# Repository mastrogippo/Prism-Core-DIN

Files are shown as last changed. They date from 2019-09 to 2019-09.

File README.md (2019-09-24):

## Prism Core boards and accessories

[Writeup and pics here](https://www.mastrogippo.it/2019/09/prism-core-boards/)

cover_pcb: Cover board layout

hv_in3: Base high voltage board for Prism Core

lato1: Left board with relay and HV detection for Prism Core

latoLV: Low voltage side board for Prism Core

top: Tob board with SKW92 module for Prism Core

top_hk2: Top board with HiLink module and RTC for Prism Core

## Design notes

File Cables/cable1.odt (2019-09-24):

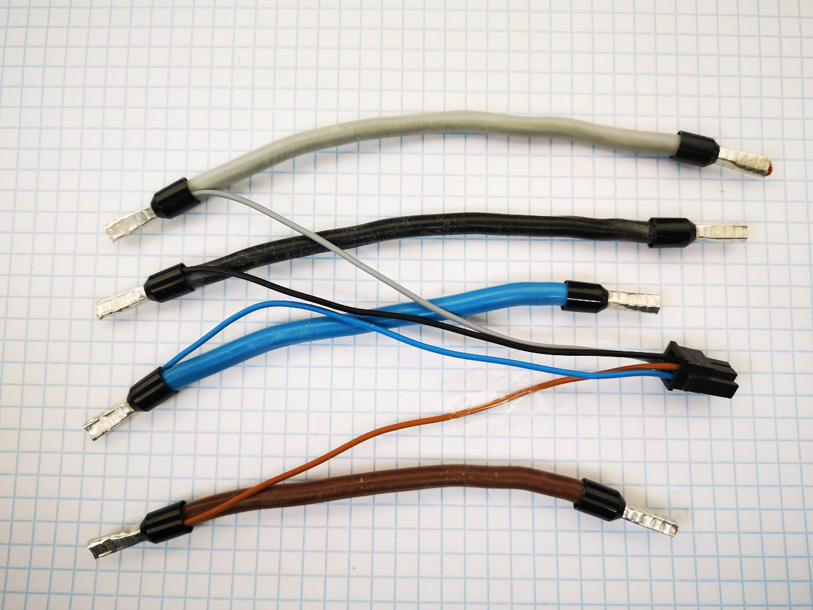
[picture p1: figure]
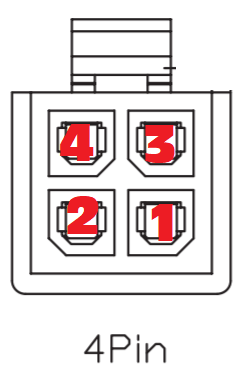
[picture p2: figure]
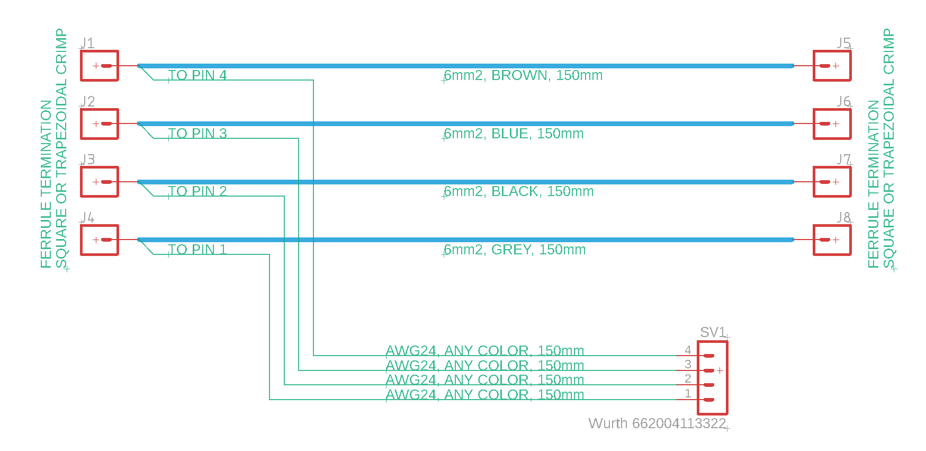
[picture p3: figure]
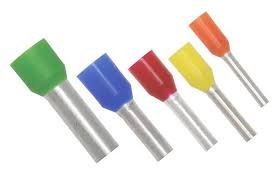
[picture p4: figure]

Connector: Wurth Electronics 662004113322
PINOUT SHOWN FROM BACK OF CONNECTOR

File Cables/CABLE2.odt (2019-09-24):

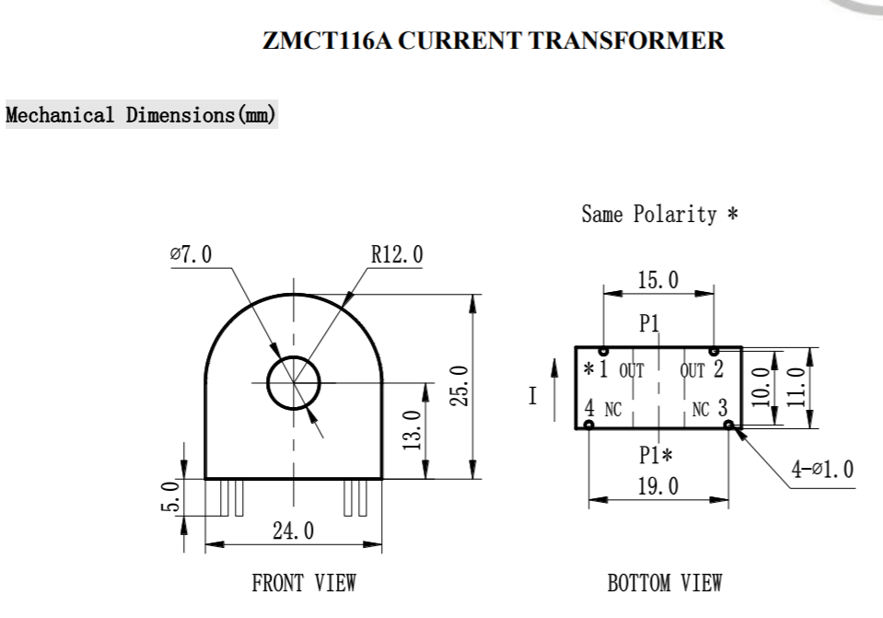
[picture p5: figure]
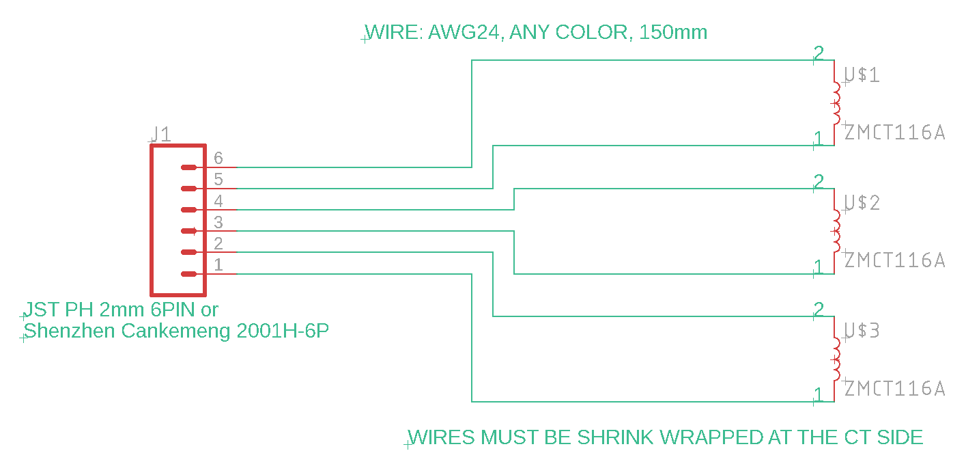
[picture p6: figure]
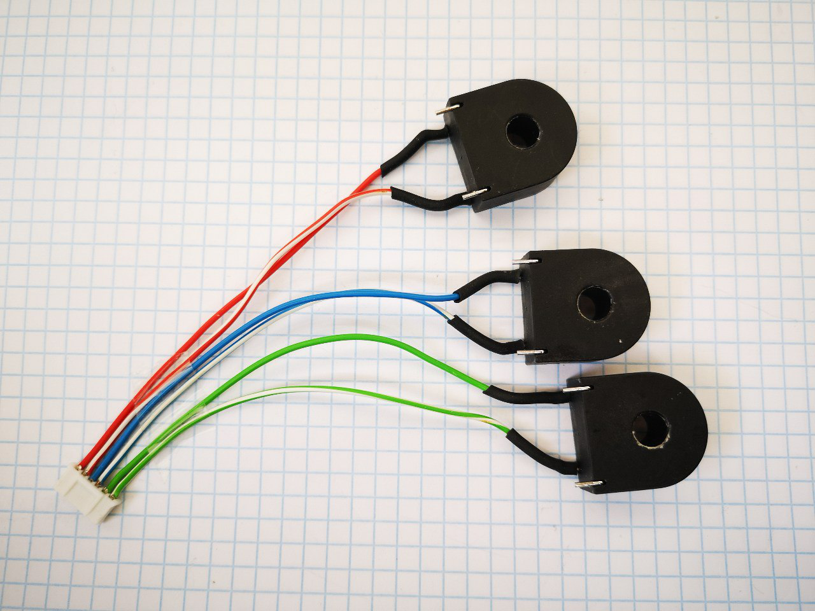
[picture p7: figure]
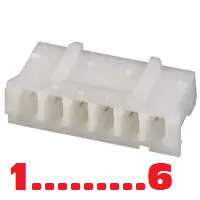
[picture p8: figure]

CONNECTOR:

SC 2001H-6P

https://lcsc.com/product-detail/_Shenzhen-Cankemeng-2001H-6P_C132488.html

(https://www.digikey.it/products/en?mpart=PHR-6&v=455)

JST PHR-6

https://www.digikey.it/products/en?mpart=PHR-6&v=455

WIRES MUST BE SHRINK WRAPPED AT THE CT SIDE (SEE PICTURE)

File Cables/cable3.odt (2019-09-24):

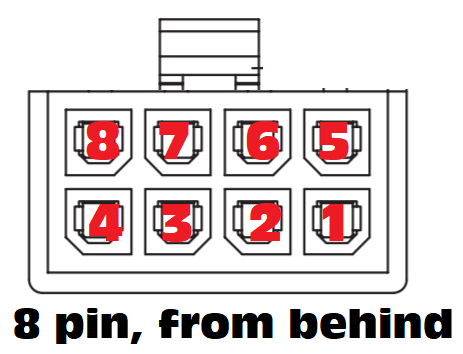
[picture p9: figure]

CONNECTOR: WURTH 662 008 113 322

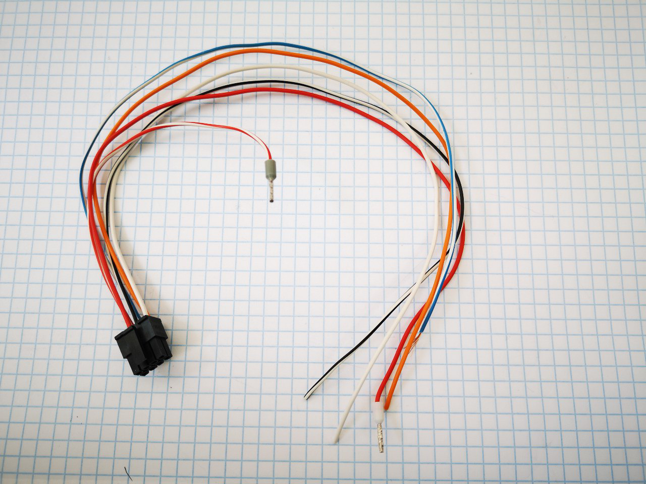
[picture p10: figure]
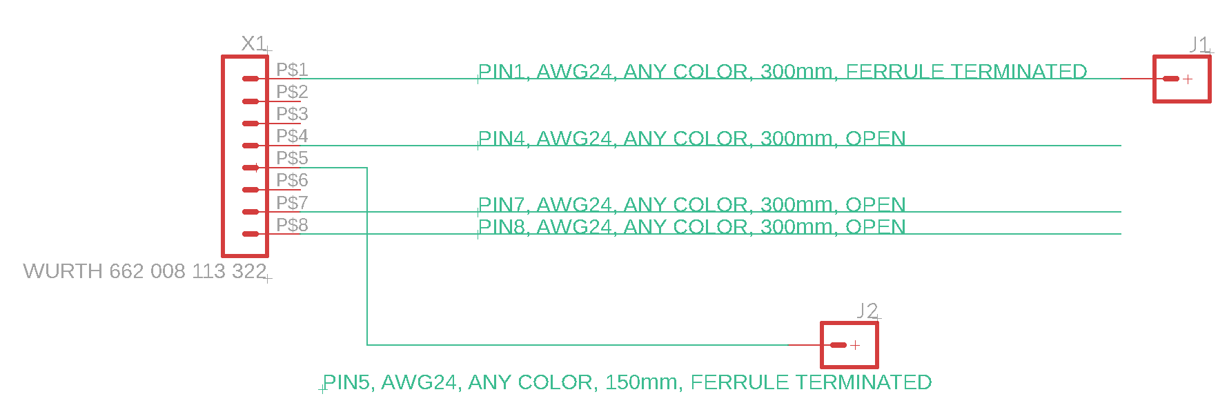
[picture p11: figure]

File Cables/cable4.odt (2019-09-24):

WARNING! PINS ARE INVERTED FROM ONE CONNECTOR 1 TO CONNECTOR 2 (1-4, 2-3, 3-2, 4-1, NOTE INVERTED CONNECTOR IN PICTURE)

https://lcsc.com/product-detail/_Shenzhen-Cankemeng-2001H-4P_C126370.html

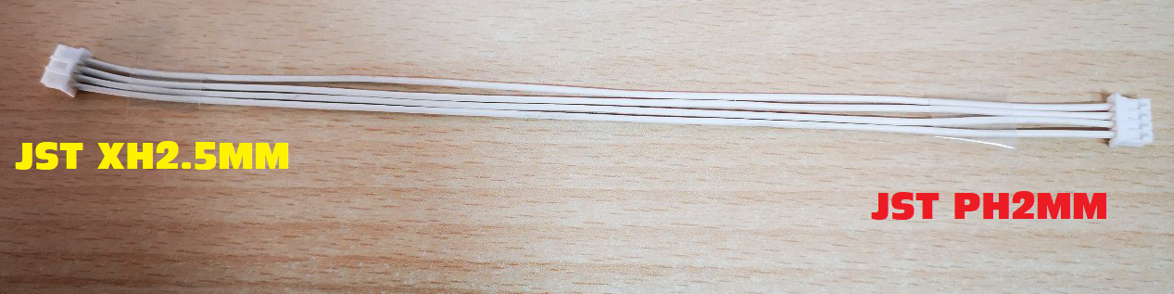
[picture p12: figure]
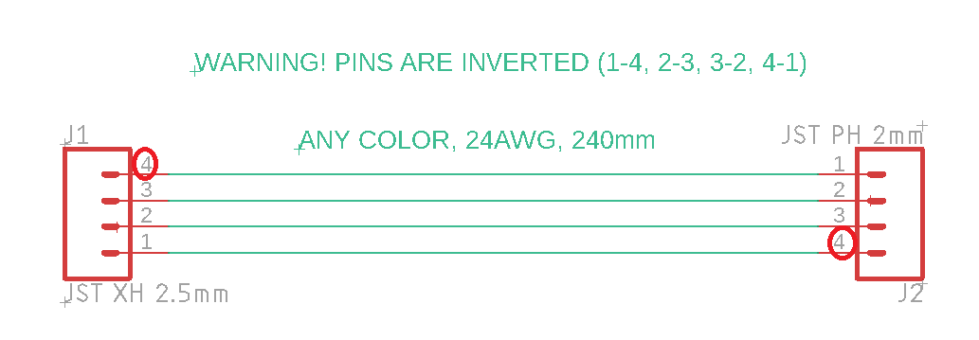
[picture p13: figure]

https://lcsc.com/product-detail/_JST-Sales-America_XHP-4_JST-Sales-America-XHP-4_C144403.html

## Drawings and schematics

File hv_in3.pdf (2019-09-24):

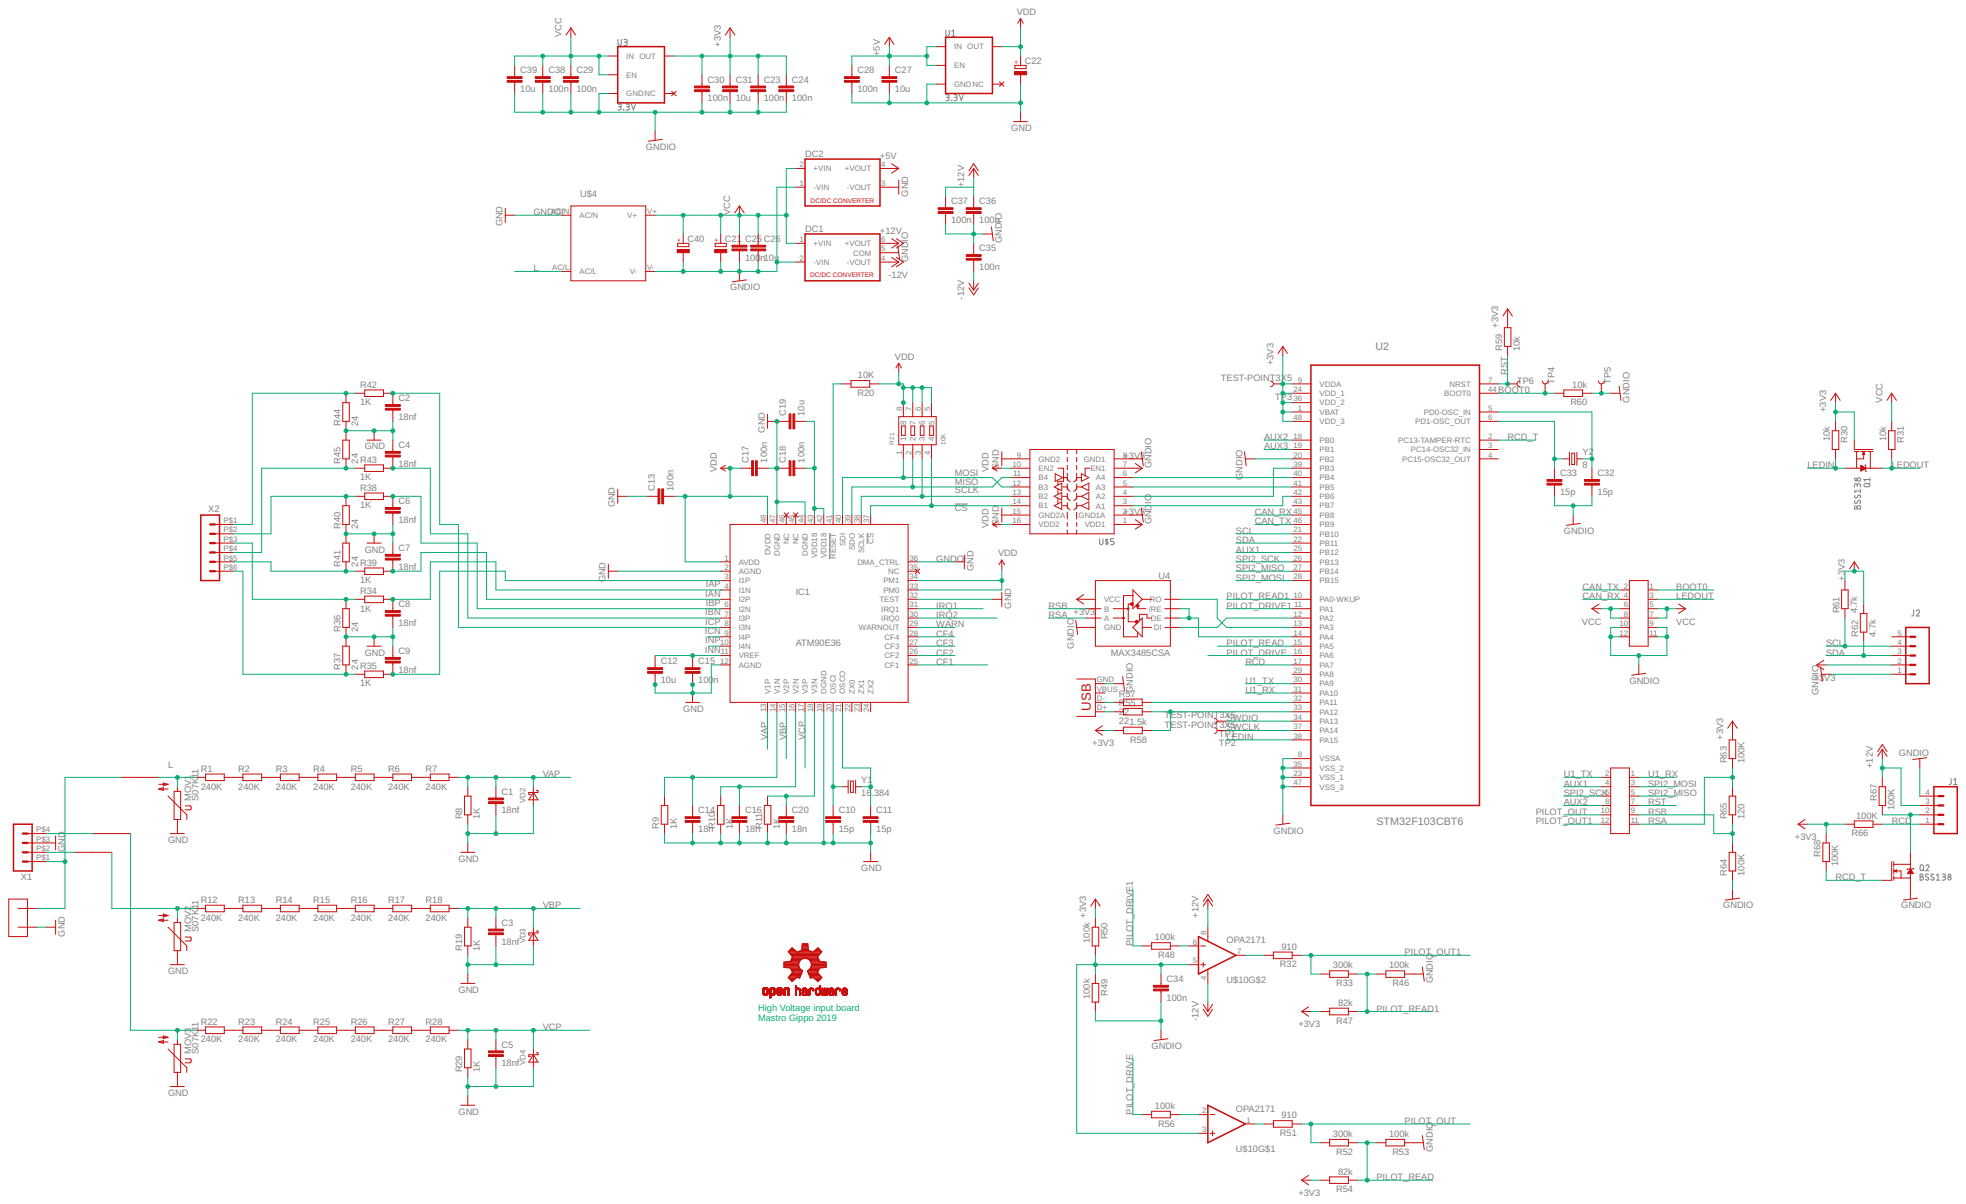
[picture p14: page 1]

+ High Voltage input board Mastro Gippo 2019

SCLK CSMOSI MISO | 7 GND1A 5 A4

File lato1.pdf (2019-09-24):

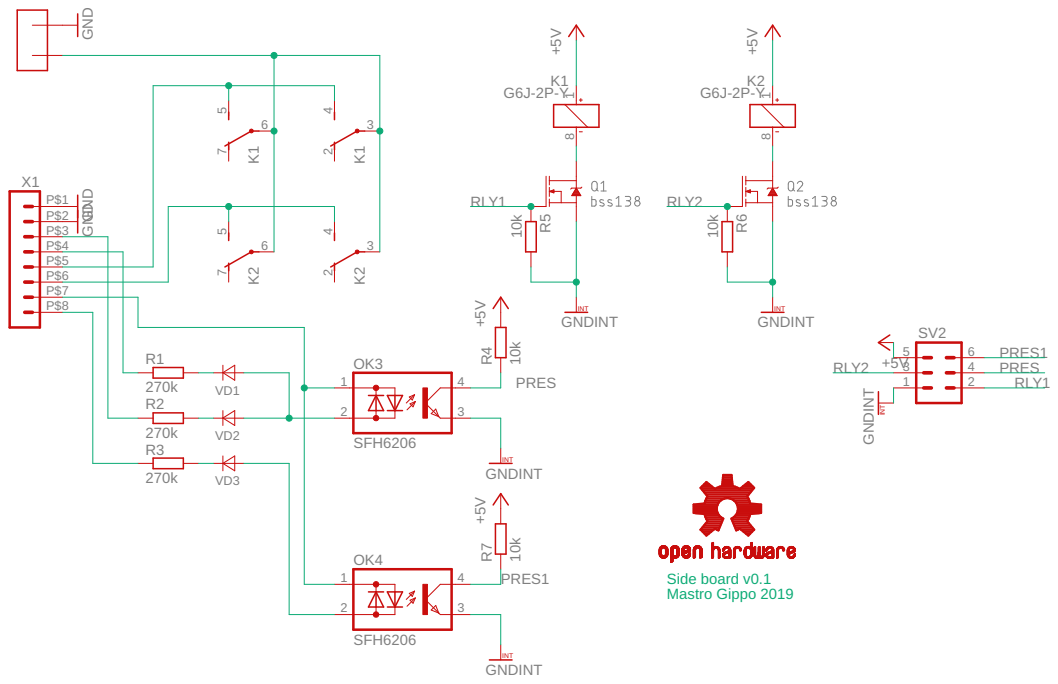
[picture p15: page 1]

GND G6J-2P-Y G6J-2P-Y GND 270k 270k 270k GND +5V +5V 10k 10k 10k +5V GNDINT GNDINT GNDINT GNDINT +5V +5V 10k GNDINT SFH6206 SFH6206 P$1 P$2 P$3 P$4 P$5 P$6 P$7 P$8 X1 8 1 K1 2 4 3K71 5 6K1 8 1 K2 2 4 3K72 5 6K2 R1 R2 R3 135 246 SV2 VD2 VD1 VD3 R4 R5 R6 R7 12 34 OK3 12 34 OK4 PRES PRES RLY1 RLY1 RLY2 RLY2 PRES1 PRES1 INT INT INT INT INT Side board v0.1 Mastro Gippo 2019

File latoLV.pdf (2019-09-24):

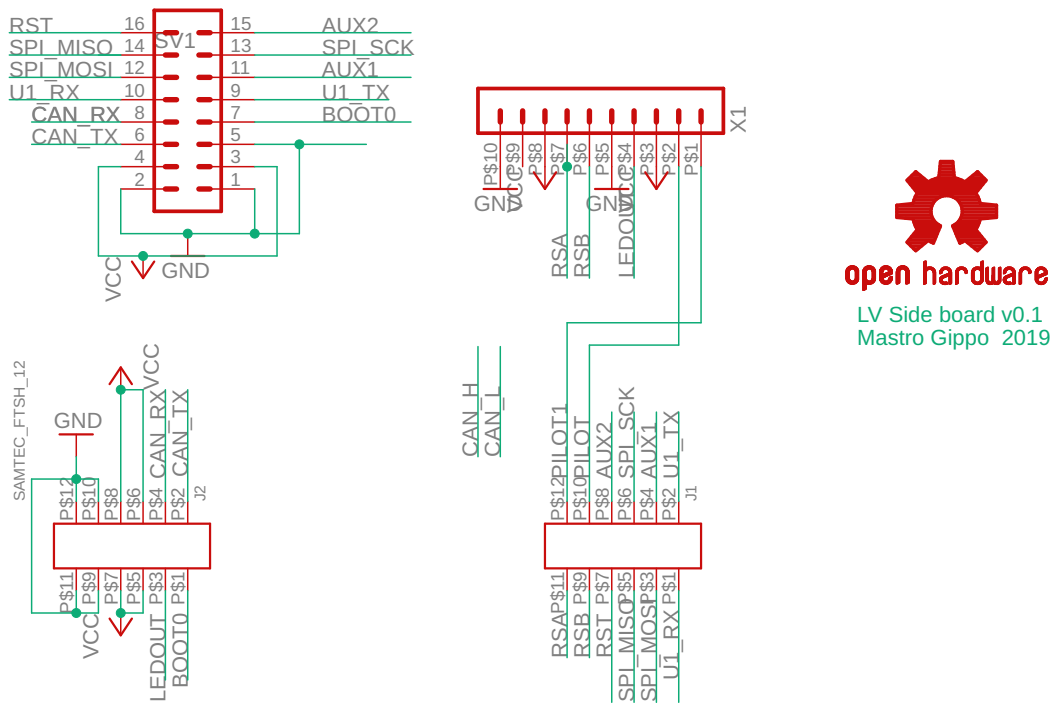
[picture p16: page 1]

SAMTEC_FTSH_12 GNDVCC VCC GND VCC VCC VCC GND GND P$1 P$2 P$3 P$4 P$5 P$6 P$7 P$8 P$9 P$10 P$11 P$12 J1 P$1 P$2 P$3 P$4 P$5 P$6 P$7 P$8 P$9 P$10 P$11 P$12 J2 135 246 79 810 111315 121416 SV1 P$1 P$2 P$3 P$4 P$5 P$6 P$7 P$8 P$9 P$10 X1 CAN_RX CAN_RX CAN_TX CAN_TX LEDOUT LEDOUT BOOT0 BOOT0 RSA RSA RSB RSB RST RST SPI_MISO SPI_MISO SPI_MOSI SPI_MOSI U1_RX U1_RX U1_TX U1_TX AUX1 AUX1 SPI_SCK SPI_SCK AUX2 AUX2 PILOT PILOT1 CAN_H CAN_L LV Side board v0.1 Mastro Gippo 2019

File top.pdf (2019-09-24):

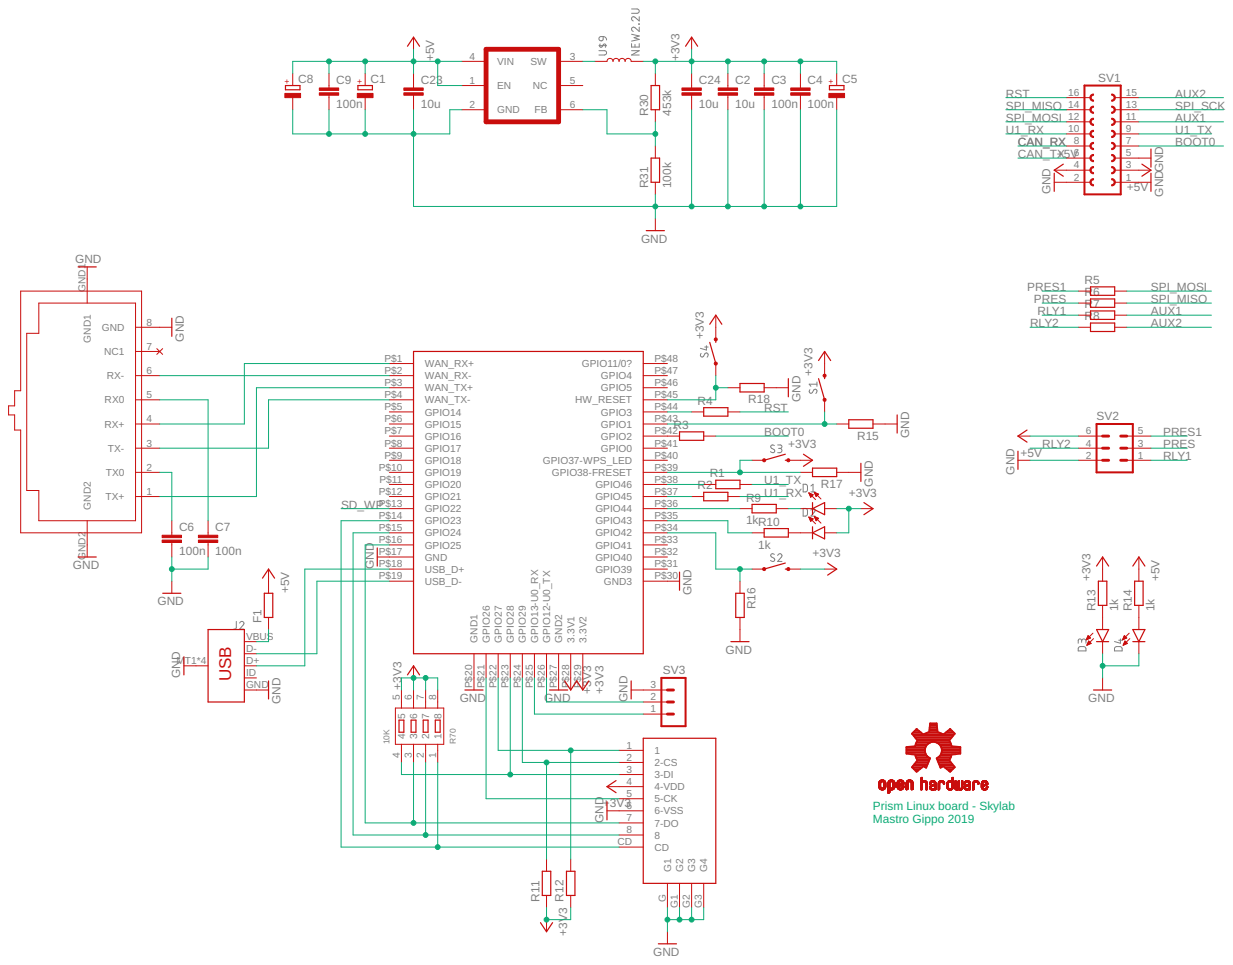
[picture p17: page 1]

3-DI 3

Prism Linux board - Skylab
Mastro Gippo 2019

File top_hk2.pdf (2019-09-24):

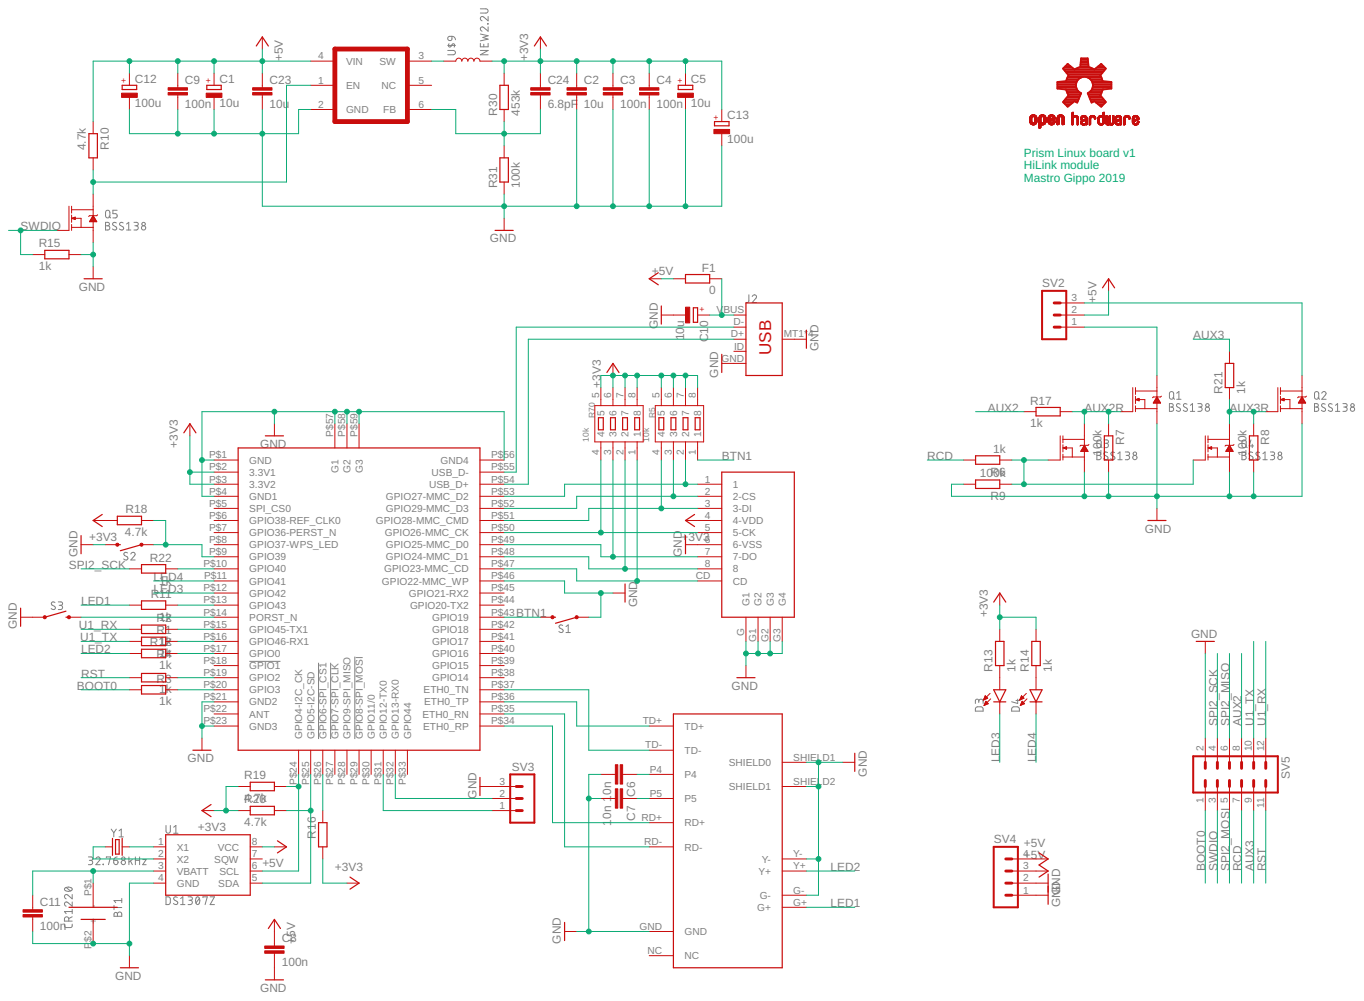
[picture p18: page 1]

Prism Linux board v1
HiLink module Mastro Gippo 2019

P$50 GPIO27-MMC_D2 P$53 GPIO28-MMC_CMD | 3-DI 3

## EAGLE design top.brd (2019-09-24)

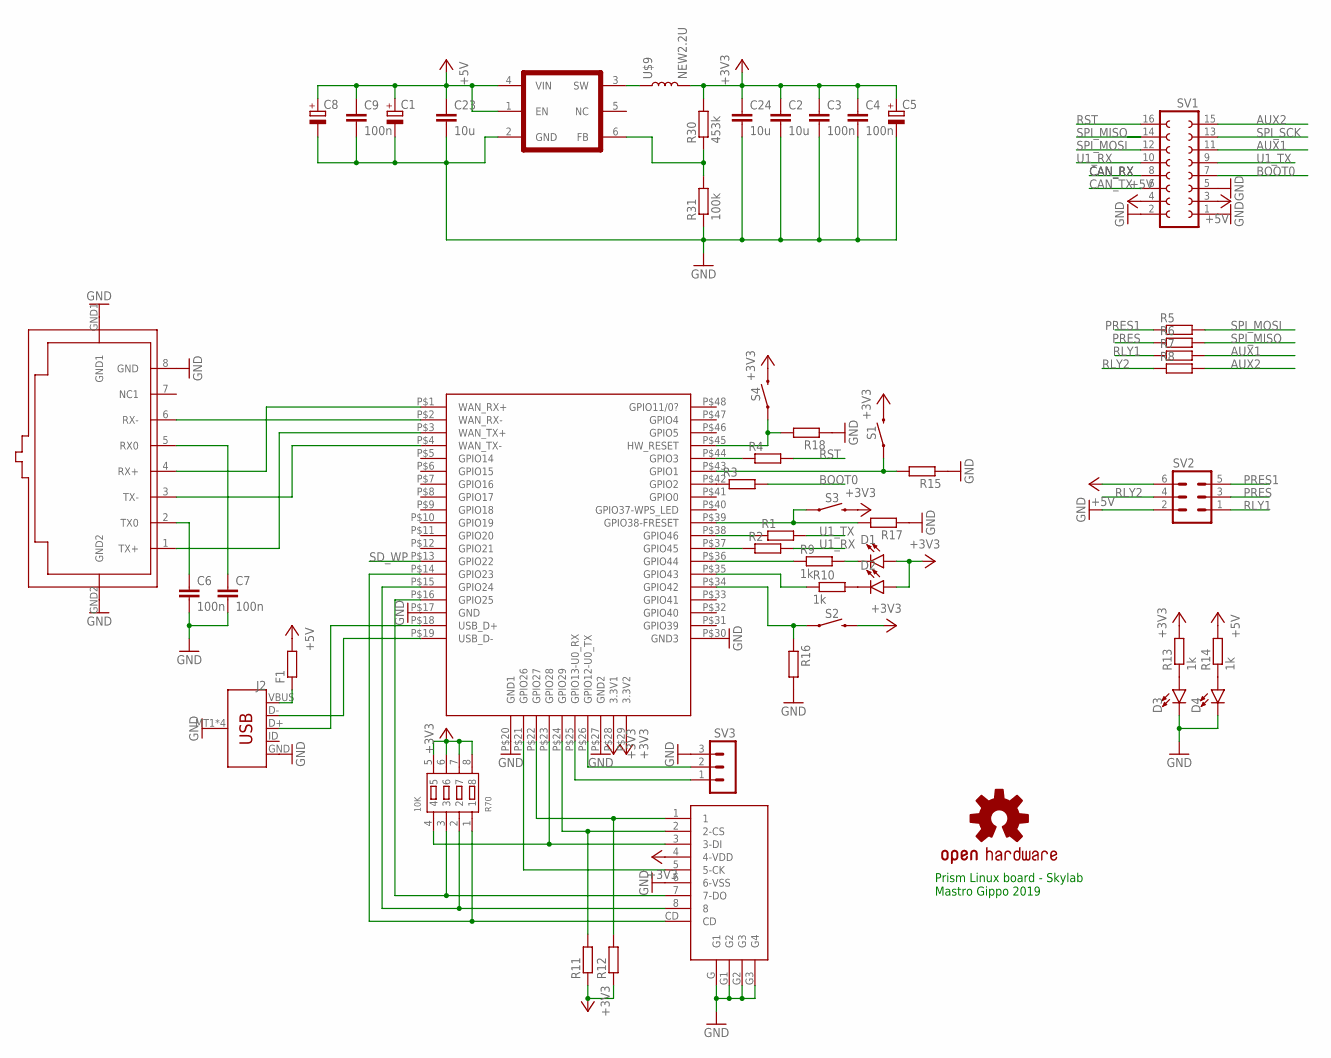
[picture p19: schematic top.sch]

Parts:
C1, C5, C8: CPOL-EUB/3528-21R; B/3528-21R
C2, C23, C24: 10u; C0805K
C3, C4, C6, C7, C9: 100n; C0805K
D1, D2: LED3MM; LED_3MM
D3, D4: LED1206; LED-1206
F1: R-EU_R0603; R0603
J2: USB_MICRO-B_SMT; USB-MICROB
R1, R2, R3, R4, R5, R6, R7, R8, R11, R12, R15, R16, R17, R18: R-EU_R0805; R0805
R9, R10, R13, R14: 1k; R0805
R30: 453k; R0805
R31: 100k; R0805
R70: 10K; RA1206-8
S1, S2, S4: MOMENTARY-SWITCH-SPST-SMD-6.0X3.5MM; TACTILE_SWITCH_SMD_6.0X3.5MM
S3: MOMENTARY-SWITCH-SPST-PTH-RIGHT-ANGLE; TACTILE_SWITCH_PTH_RIGHT_ANGLE
SV1: FE08-2
SV2: MA03-2
SV3: MA03-1
U$1: RJ45-TRAFO
U$2: SKW92B; SKW92
U$3: MICRO_SD; MICRO_SD_C
U$4: OSHW-LOGOS; OSHW-LOGO-S
U$8: TLV62658; SOT23-6
U$9: NEW2.2U; INDUCTOR_4X4MM

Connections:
+3V3: C2.1, C3.1, C4.1, C5.+, C24.1, D1.A, D2.A, R11.1, R12.1, R13.2, R30.2, R70.5, R70.6, R70.7, R70.8, S1.2, S2.2, S3.2, S4.2, U$2.P$28 (3.3V1), U$2.P$29 (3.3V2), U$3.4 (4-VDD), U$9.P$2 (2)
+5V: C1.+, C8.+, C9.1, C23.1, F1.2, R14.2, SV1.3, SV1.4, SV2.6, U$8.1 (EN), U$8.4 (VIN)
AUX1: R7.2, SV1.11
AUX2: R8.2, SV1.15
BOOT0: R3.2, SV1.7
CAN_RX: SV1.8
CAN_TX: SV1.6
GND: C1.-, C2.2, C3.2, C4.2, C5.-, C6.2, C7.2, C8.-, C9.2, C23.2, C24.2, D3.C, D4.C, J2.GND, J2.MT1 (SHIELD), J2.MT2 (SHIELD), J2.P$1 (SHIELD), J2.P$2 (SHIELD), R15.1, R16.2, R17.1, R18.1, R31.1, SV1.1, SV1.2, SV1.5, SV2.2, SV3.3, U$1.8 (GND), U$1.GND1, U$1.GND2, U$2.P$17 (GND), U$2.P$20 (GND1), U$2.P$27 (GND2), U$2.P$30 (GND3), U$3.6 (6-VSS), U$3.G (G1), U$3.G1 (G2), U$3.G2 (G3), U$3.G3 (G4), U$8.2 (GND)
unnamed: U$1.6 (RX-), U$2.P$2 (WAN_RX-)
unnamed: U$1.4 (RX+), U$2.P$1 (WAN_RX+)
unnamed: U$1.1 (TX+), U$2.P$3 (WAN_TX+)
unnamed: U$1.3 (TX-), U$2.P$4 (WAN_TX-)
unnamed: R11.2, U$2.P$24 (GPIO29), U$3.2 (2-CS)
unnamed: R70.4, U$2.P$23 (GPIO28), U$3.3 (3-DI)
unnamed: R12.2, U$2.P$22 (GPIO27), U$3.1
unnamed: U$2.P$21 (GPIO26), U$3.5 (5-CK)
unnamed: R70.3, U$2.P$16 (GPIO25), U$3.7 (7-DO)
unnamed: R70.2, U$2.P$15 (GPIO24), U$3.8
unnamed: R70.1, U$2.P$14 (GPIO23), U$3.CD
unnamed: R1.1, U$2.P$38 (GPIO46)
unnamed: R2.1, U$2.P$37 (GPIO45)
unnamed: R3.1, U$2.P$42 (GPIO2)
unnamed: R4.1, U$2.P$44 (GPIO3)
unnamed: D1.K (C), R9.2
unnamed: SV3.2, U$2.P$26 (GPIO12-U0_TX)
unnamed: SV3.1, U$2.P$25 (GPIO13-U0_RX)
unnamed: D2.K (C), R10.2
unnamed: R9.1, U$2.P$36 (GPIO44)
unnamed: R10.1, U$2.P$35 (GPIO43)
unnamed: D3.A, R13.1
unnamed: D4.A, R14.1
unnamed: R15.2, S1.1, U$2.P$43 (GPIO1)
unnamed: R16.1, S2.1, U$2.P$34 (GPIO42)
unnamed: R17.2, S3.1, U$2.P$39 (GPIO38-FRESET)
unnamed: R18.2, S4.1, U$2.P$45 (HW_RESET)
unnamed: C7.1, U$1.5 (RX0)
unnamed: C6.1, U$1.2 (TX0)
unnamed: J2.D+, U$2.P$18 (USB_D+)
unnamed: J2.D-, U$2.P$19 (USB_D-)
unnamed: F1.1, J2.VBUS
unnamed: U$8.3 (SW), U$9.P$1 (1)
unnamed: R30.1, R31.2, U$8.6 (FB)
PRES: R6.1, SV2.3
PRES1: R5.1, SV2.5
RLY1: R7.1, SV2.1
RLY2: R8.1, SV2.4
RST: R4.2, SV1.16
SD_WP: U$2.P$13 (GPIO22)
SPI_MISO: R6.2, SV1.14
SPI_MOSI: R5.2, SV1.12
SPI_SCK: SV1.13
U1_RX: R2.2, SV1.10
U1_TX: R1.2, SV1.9

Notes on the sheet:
Prism Linux board - Skylab Mastro Gippo 2019

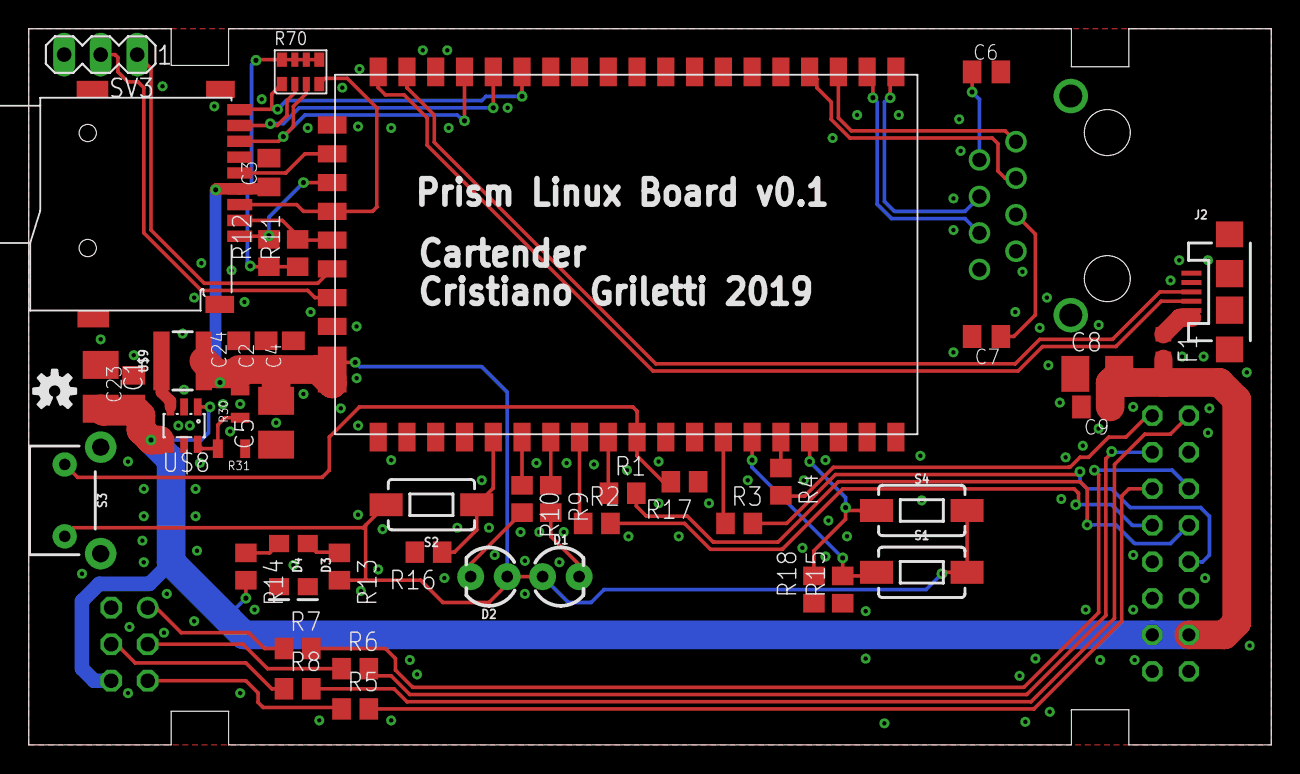
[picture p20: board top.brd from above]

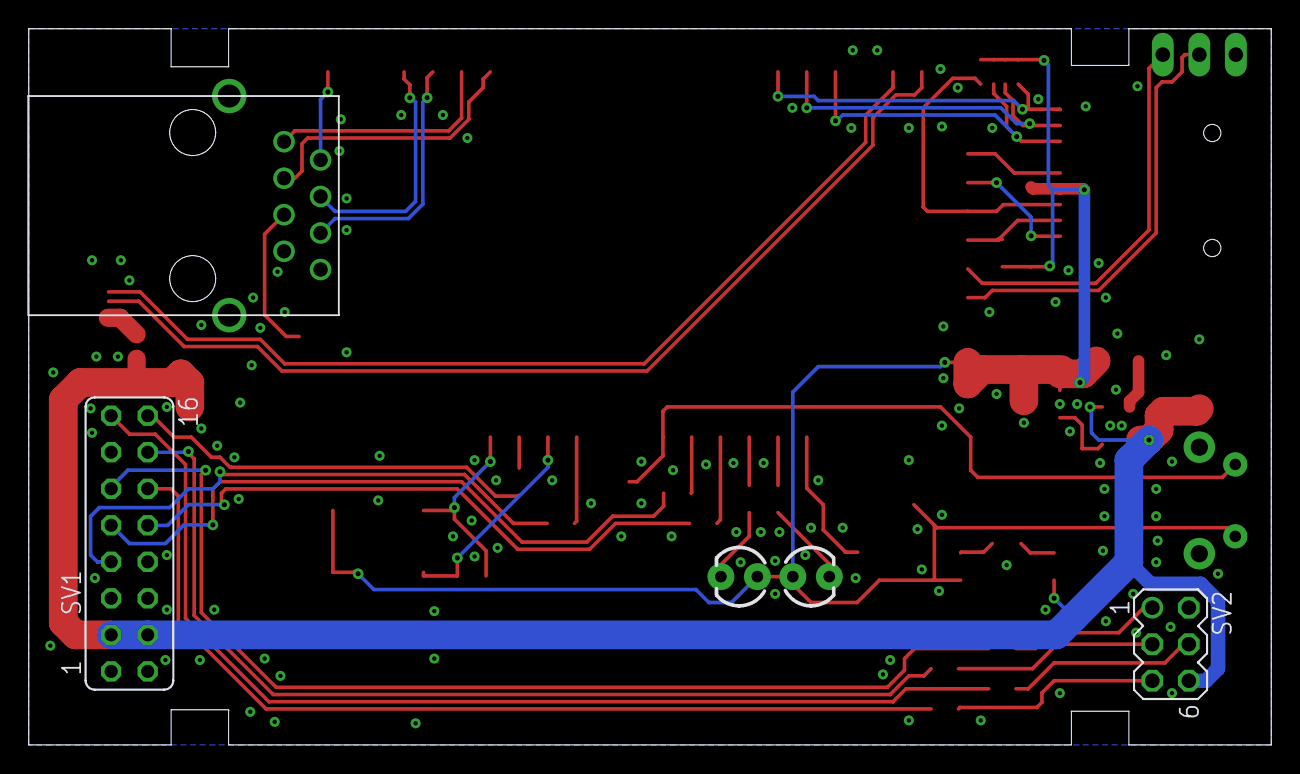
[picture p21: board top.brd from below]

Board: 2 copper layers, 86.4 x 49.8 mm, 51 parts (3 on the bottom side), 49 nets.

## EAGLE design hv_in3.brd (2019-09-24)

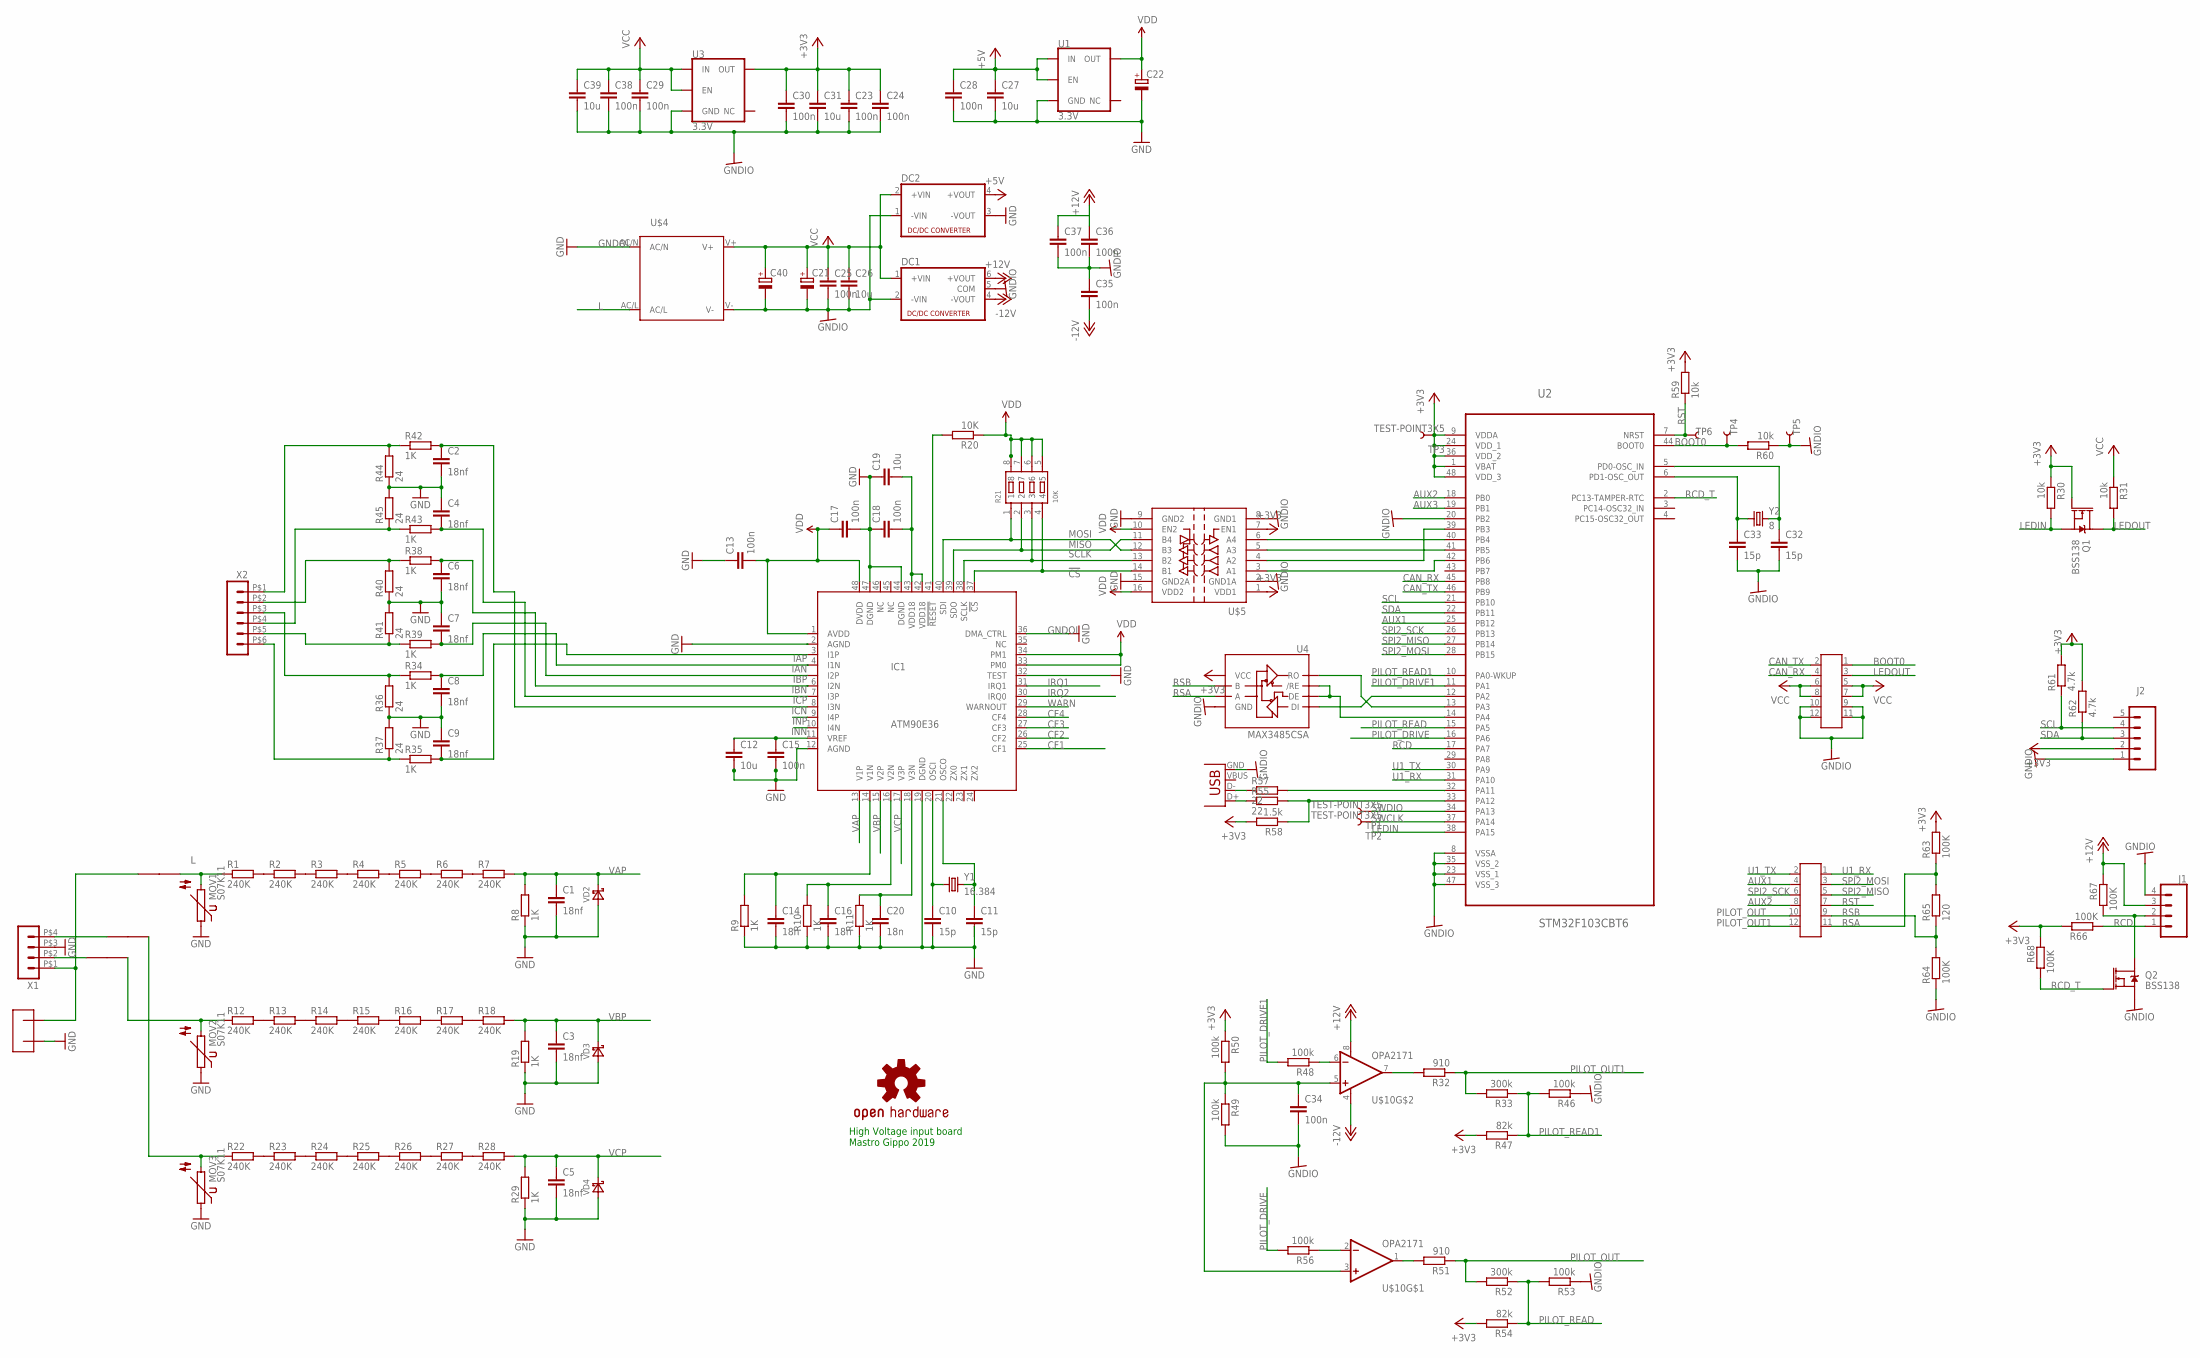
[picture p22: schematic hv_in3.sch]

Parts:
C1, C2, C3, C4, C5, C6, C7, C8, C9: 18nf; C0805K
C10, C11, C32, C33: 15p; C0805K
C12, C19, C26, C27, C31, C39: 10u; C0805K
C13, C15, C17, C18, C23, C24, C25, C28, C29, C30, C34, C35, C36, C37, C38: 100n; C0805K
C14, C16, C20: 18n; C0805K
C21, C22: CPOL-EU153CLV-0505; 153CLV-0505
C40: CPOL-EUB/3528-21R; B/3528-21R
DC1: NMA
DC2: NME
IC1: ATM90E36; TQFP48
J1: CONN_04SMD2; 1X04_1MM_RA
J2: CONN_05SMD2; 1X05_1MM_RA
MOV1, MOV2, MOV3: S07K11
Q1, Q2: BSS138; SOT23-3
R1, R2, R3, R4, R5, R6, R7, R12, R13, R14, R15, R16, R17, R18, R22, R23, R24, R25, R26, R27, R28: 240K; R0805
R8, R9, R10, R11, R19, R29, R34, R35, R38, R39, R42, R43: 1K; R0805
R20: 10K; R0805
R21: 10K; RA1206-8
R30, R31, R59, R60: 10k; R0805
R32, R51: 910; R1206
R33, R52: 300k; R0805
R36, R37, R40, R41, R44, R45: 24; R0805
R46, R48, R49, R50, R53, R56: 100k; R0805
R47, R54: 82k; R0805
R55, R57: 22; R0805
R58: 1.5k; R0805
R61, R62: 4.7k; R0805
R63, R64, R66, R67, R68: 100K; R0805
R65: 120; R0805
TP1, TP2, TP3, TP4, TP5, TP6: TEST-POINT3X5; PAD.03X.05
U1, U3: 3.3V; SOT23-5
U2: STM32F103CBT6; QFP50P900X900X160-48N
U4: MAX3485CSA; SO08
U$1, U$2, U$3: FUSE_2410; 2410_F
U$4: IRM_15/20IRM_15/20; IRM_15/20
U$5: SI8441IS1; SO16
U$6: ISOLATED_2P; STRIP_NOMIDDLE
U$7, U$8: CLP-106-02-F-D-P; CLP-106-02-X-D
U$9: OSHW-LOGOS; OSHW-LOGO-S
U$10: OPA2171; SO08
VD2, VD3, VD4: DIODE-SCHOTTKY-SOD523; SOD523
X1: HEADER_POS4_43045-0401; 43045-0400
X2: HEADER_POS6_43045-0600; 43045-0600
X3: USB-MICROB
Y1: 16.384; CRYSTAL-SMD-3.2X2.5MM
Y2: 8; CRYSTAL-SMD-3.2X2.5MM

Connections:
!CS: IC1.37 (!CS), R21.4, U$5.14 (B1)
+3V3: C23.1, C24.1, C30.1, C31.1, J2.2, Q1.1 (G), R30.1, R47.2, R50.1, R54.2, R58.2, R59.2, R61.2, R62.2, R63.2, R66.2, R68.2, TP3.P$1, U2.1 (VBAT), U2.9 (VDDA), U2.24 (VDD_1), U2.36 (VDD_2), U2.48 (VDD_3), U3.5 (OUT), U4.8 (VCC), U$5.1 (VDD1), U$5.7 (EN1)
+5V: C27.1, C28.1, DC2.4 (+VOUT), U1.1 (IN), U1.3 (EN)
+12V: C36.1, C37.1, DC1.6 (+VOUT), J1.3, R67.2, U$10.8 (V+)
-12V: C35.2, DC1.4 (-VOUT), U$10.4 (V-)
AUX1: U2.25 (PB12), U$7.4
AUX2: U2.18 (PB0), U$7.8
AUX3: U2.19 (PB1)
BOOT0: R60.2, TP4.P$1, U2.44 (BOOT0), U$8.1
CAN_RX: U2.45 (PB8), U$8.4
CAN_TX: U2.46 (PB9), U$8.2
CF1: IC1.25 (CF1)
CF2: IC1.26 (CF2)
CF3: IC1.27 (CF3)
CF4: IC1.28 (CF4)
GNDIO: C21.-, C23.2, C24.2, C25.2, C26.2, C29.2, C30.2, C31.2, C32.2, C33.2, C34.2, C35.1, C36.2, C37.2, C38.2, C39.2, C40.-, DC1.2 (-VIN), DC1.5 (COM), DC2.1 (-VIN), J1.4, J2.1, Q2.2 (S), R46.1, R49.2, R53.1, R60.1, R64.1, TP5.P$1, U2.8 (VSSA), U2.20 (PB2), U2.23 (VSS_1), U2.35 (VSS_2), U2.47 (VSS_3), U3.2 (GND), U4.5 (GND), U$4.V-, U$5.2 (GND1A), U$5.8 (GND1), U$8.9, U$8.10, U$8.11, U$8.12, X3.GND
GNDOI: C1.2, C2.2, C3.2, C4.1, C5.2, C6.2, C7.1, C8.2, C9.1, C10.2, C11.2, C12.2, C13.1, C14.2, C15.2, C16.2, C17.2, C18.1, C19.1, C20.2, C22.-, C27.2, C28.2, DC2.3 (-VOUT), IC1.2 (AGND), IC1.12 (AGND), IC1.19 (DGND), IC1.32 (TEST), IC1.36 (DMA_CTRL), IC1.44 (DGND), IC1.47 (DGND), MOV1.1, MOV2.1, MOV3.1, R8.1, R9.1, R10.1, R11.1, R19.1, R29.1, R36.1, R37.2, R40.1, R41.2, R44.1, R45.2, U1.2 (GND), U$4.AC/N, U$5.9 (GND2), U$5.15 (GND2A), U$6.P$2, VD2.A, VD3.A, VD4.A, X1.P$3 (3)
IAN: C8.1, IC1.4 (I1N), R34.2
IAP: C9.2, IC1.3 (I1P), R35.2
IBN: C6.1, IC1.6 (I2N), R38.2
IBP: C7.2, IC1.5 (I2P), R39.2
ICN: C2.1, IC1.8 (I3N), R42.2
ICP: C4.2, IC1.7 (I3P), R43.2
INN: IC1.10 (I4N)
INP: IC1.9 (I4P)
IRQ1: IC1.31 (IRQ1)
IRQ2: IC1.30 (IRQ0)
L: MOV1.2, R1.1, U$1.P$2, U$4.AC/L
LEDIN: Q1.2 (S), R30.2, U2.38 (PA15)
LEDOUT: Q1.3 (D), R31.2, U$8.3
MISO: IC1.39 (SDO), R21.2, U$5.11 (B4)
MOSI: IC1.40 (SDI), R21.1, U$5.12 (B3)
unnamed: U$3.P$2, X1.P$4 (4)
unnamed: R1.2, R2.1
unnamed: R2.2, R3.1
unnamed: R3.2, R4.1
unnamed: R4.2, R5.1
unnamed: R5.2, R6.1
unnamed: R6.2, R7.1
unnamed: U$2.P$2, X1.P$2 (2)
unnamed: MOV2.2, R12.1, U$2.P$1
unnamed: C32.1, U2.5 (PD0-OSC_IN), Y2.3 (2)
unnamed: C33.1, U2.6 (PD1-OSC_OUT), Y2.1
unnamed: U$1.P$1, U$6.P$1, X1.P$1 (1)
unnamed: U2.40 (PB4), U$5.6 (A4)
unnamed: U2.41 (PB5), U$5.5 (A3)
unnamed: R12.2, R13.1
unnamed: R13.2, R14.1
unnamed: R14.2, R15.1
unnamed: R15.2, R16.1
unnamed: R16.2, R17.1
unnamed: R17.2, R18.1
unnamed: C14.1, IC1.14 (V1N), R9.2
unnamed: C16.1, IC1.16 (V2N), R10.2
unnamed: U2.39 (PB3), U$5.4 (A2)
unnamed: C20.1, IC1.18 (V3N), R11.2
unnamed: MOV3.2, R22.1, U$3.P$1
unnamed: R22.2, R23.1
unnamed: R23.2, R24.1
unnamed: R24.2, R25.1
unnamed: R25.2, R26.1
unnamed: R26.2, R27.1
unnamed: R27.2, R28.1
unnamed: C18.2, C19.2, IC1.42 (VDD18), IC1.43 (VDD18)
unnamed: C10.1, IC1.20 (OSCI), Y1.1
unnamed: C11.1, IC1.21 (OSCO), Y1.3 (2)
unnamed: R34.1, R36.2, X2.P$3 (3)
unnamed: R39.1, R41.1, X2.P$5 (5)
unnamed: U2.42 (PB6), U$5.3 (A1)
unnamed: R55.1, X3.D+
unnamed: R57.1, X3.D-
unnamed: R43.1, R45.1, X2.P$4 (4)
unnamed: R57.2, U2.32 (PA11)
unnamed: R35.1, R37.1, X2.P$6 (6)
unnamed: R42.1, R44.2, X2.P$1 (1)
unnamed: R55.2, R58.1, U2.33 (PA12)
unnamed: R51.2, U$10.1 (OUT)
unnamed: R56.1, U$10.2 (-IN)
unnamed: R38.1, R40.2, X2.P$2 (2)
unnamed: R48.1, U$10.6 (-IN)
unnamed: C34.1, R49.1, R50.2, U$10.3 (+IN), U$10.5 (+IN)
unnamed: R32.2, U$10.7 (OUT)
unnamed: U2.12 (PA2), U4.4 (DI)
unnamed: U2.13 (PA3), U4.1 (RO)
unnamed: C12.1, C15.1, IC1.11 (VREF)
unnamed: U2.14 (PA4), U4.2 (/RE), U4.3 (DE)
unnamed: J1.2, Q2.3 (D), R67.1
PILOT_DRIVE: R56.2, U2.16 (PA6)
PILOT_DRIVE1: R48.2, U2.11 (PA1)
PILOT_OUT: R51.1, R52.2, U$7.10
PILOT_OUT1: R32.1, R33.2, U$7.12
PILOT_READ: R52.1, R53.2, R54.1, U2.15 (PA5)
PILOT_READ1: R33.1, R46.2, R47.1, U2.10 (PA0-WKUP)
RCD: J1.1, R66.1, U2.17 (PA7)
RCD_T: Q2.1 (G), R68.1, U2.2 (PC13-TAMPER-RTC)
RES: IC1.41 (!RESET), R20.2
RSA: R63.1, R65.2, U4.6 (A), U$7.11
RSB: R64.2, R65.1, U4.7 (B), U$7.9
RST: R59.1, TP6.P$1, U2.7 (NRST), U$7.7
SCL: J2.4, R61.1, U2.21 (PB10)
SCLK: IC1.38 (SCLK), R21.3, U$5.13 (B2)
SDA: J2.3, R62.1, U2.22 (PB11)
SPI2_MISO: U2.27 (PB14), U$7.5
SPI2_MOSI: U2.28 (PB15), U$7.3
SPI2_SCK: U2.26 (PB13), U$7.6
SWCLK: TP2.P$1, U2.37 (PA14)
SWDIO: TP1.P$1, U2.34 (PA13)
U1_RX: U2.31 (PA10), U$7.1
U1_TX: U2.30 (PA9), U$7.2
VAP: C1.1, IC1.13 (V1P), R7.2, R8.2, VD2.C
VBP: C3.1, IC1.15 (V2P), R18.2, R19.2, VD3.C
VCC: C21.+, C25.1, C26.1, C29.1, C38.1, C39.1, C40.+, DC1.1 (+VIN), DC2.2 (+VIN), R31.1, U3.1 (IN), U3.3 (EN), U$4.V+, U$8.5, U$8.6, U$8.7, U$8.8
VCP: C5.1, IC1.17 (V3P), R28.2, R29.2, VD4.C
VDD: C13.2, C17.1, C22.+, IC1.1 (AVDD), IC1.33 (PM0), IC1.34 (PM1), IC1.48 (DVDD), R20.1, R21.5, R21.6, R21.7, R21.8, U1.5 (OUT), U$5.10 (EN2), U$5.16 (VDD2)
WARN: IC1.29 (WARNOUT)

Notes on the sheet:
High Voltage input board Mastro Gippo 2019

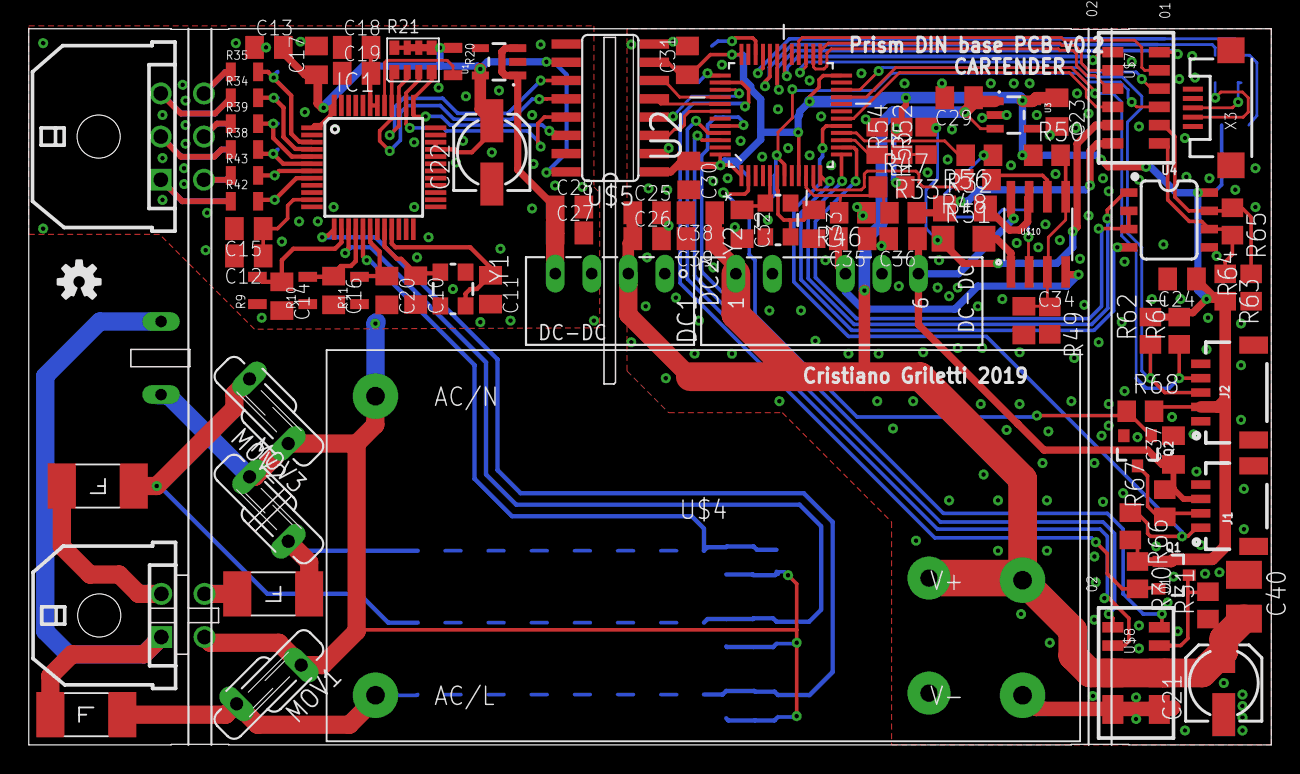
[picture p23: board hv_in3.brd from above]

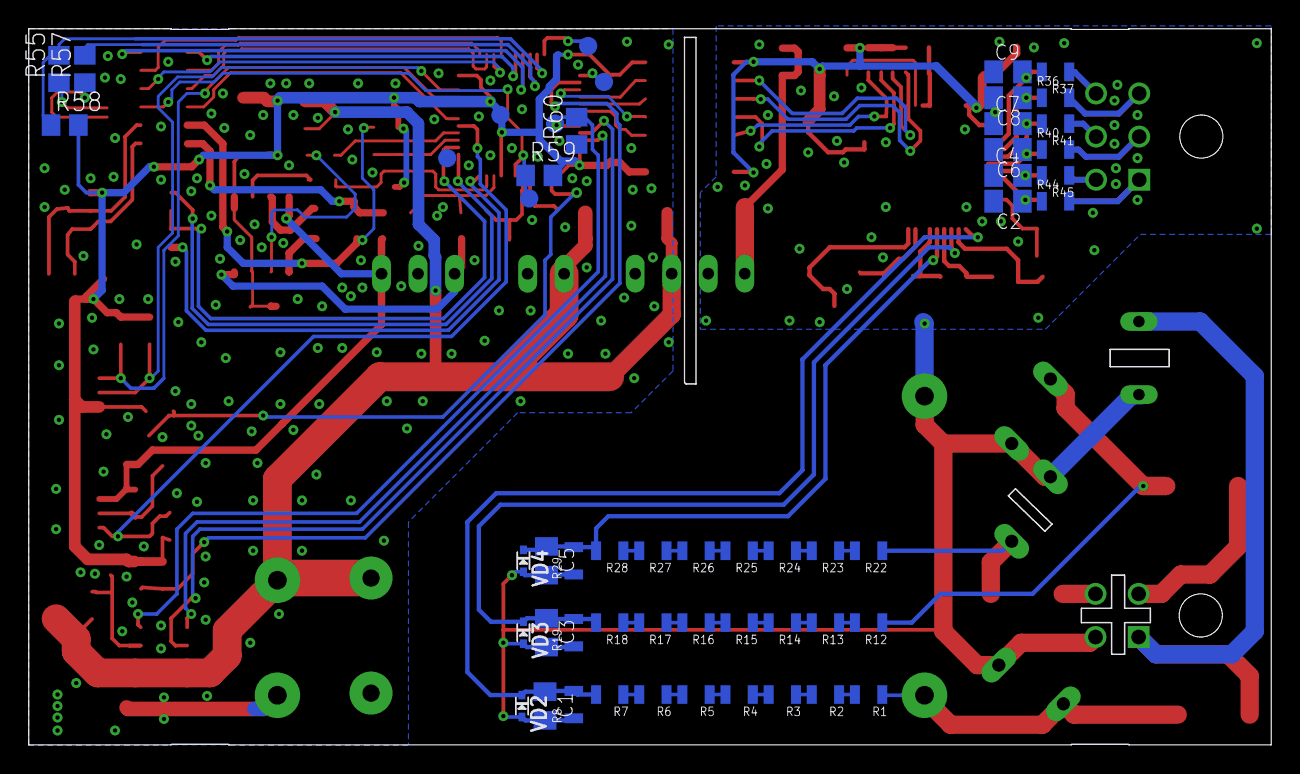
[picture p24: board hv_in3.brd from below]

Board: 2 copper layers, 86.4 x 49.8 mm, 146 parts (53 on the bottom side), 105 nets.

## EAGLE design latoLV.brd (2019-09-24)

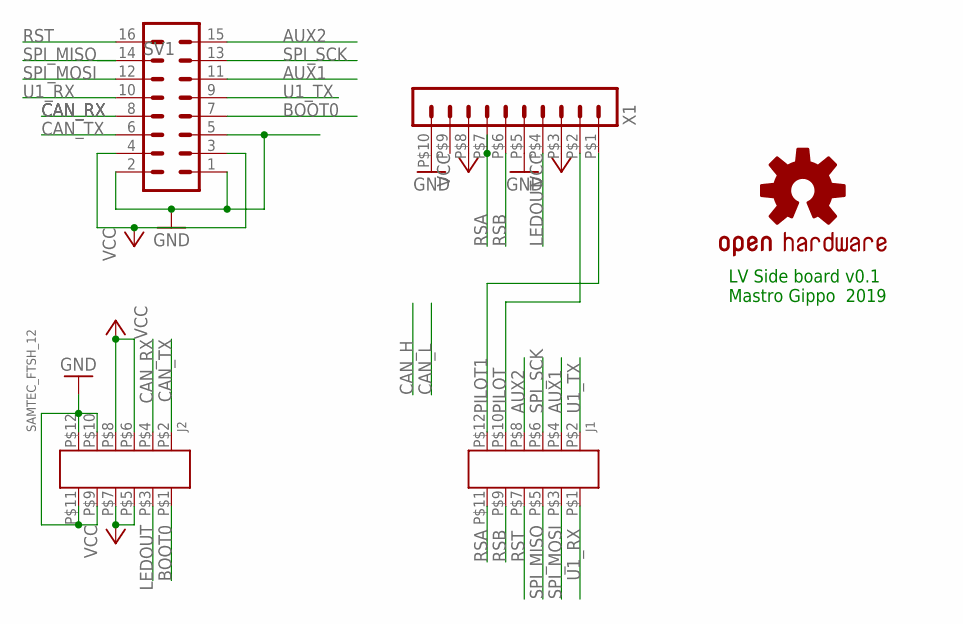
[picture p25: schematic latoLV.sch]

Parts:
J1, J2: SAMTEC_FTSH_12; 6X2_1MM
SV1: MA08-2
U$1: OSHW-LOGOS; OSHW-LOGO-S
X1: HEADER_POS10_43045-1012; 43045-1012

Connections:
AUX1: J1.P$4, SV1.11
AUX2: J1.P$8, SV1.15
BOOT0: J2.P$1, SV1.7
CAN_RX: J2.P$4, SV1.8
CAN_TX: J2.P$2, SV1.6
GND: J2.P$9, J2.P$10, J2.P$11, J2.P$12, SV1.1, SV1.2, SV1.5, X1.P$5 (5), X1.P$10 (10)
LEDOUT: J2.P$3, X1.P$4 (4)
PILOT: J1.P$10, X1.P$2 (2)
PILOT1: J1.P$12, X1.P$1 (1)
RSA: J1.P$11, X1.P$7 (7)
RSB: J1.P$9, X1.P$6 (6)
RST: J1.P$7, SV1.16
SPI_MISO: J1.P$5, SV1.14
SPI_MOSI: J1.P$3, SV1.12
SPI_SCK: J1.P$6, SV1.13
U1_RX: J1.P$1, SV1.10
U1_TX: J1.P$2, SV1.9
VCC: J2.P$5, J2.P$6, J2.P$7, J2.P$8, SV1.3, SV1.4, X1.P$3 (3), X1.P$8 (8)

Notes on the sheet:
LV Side board v0.1 Mastro Gippo 2019

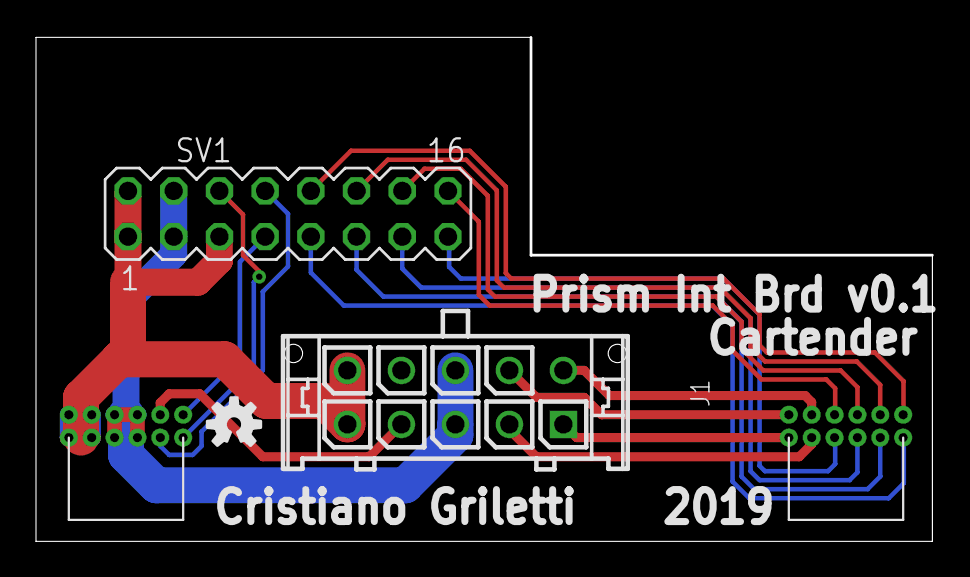
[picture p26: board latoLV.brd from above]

Board: 2 copper layers, 49.8 x 28.0 mm, 5 parts (0 on the bottom side), 18 nets.

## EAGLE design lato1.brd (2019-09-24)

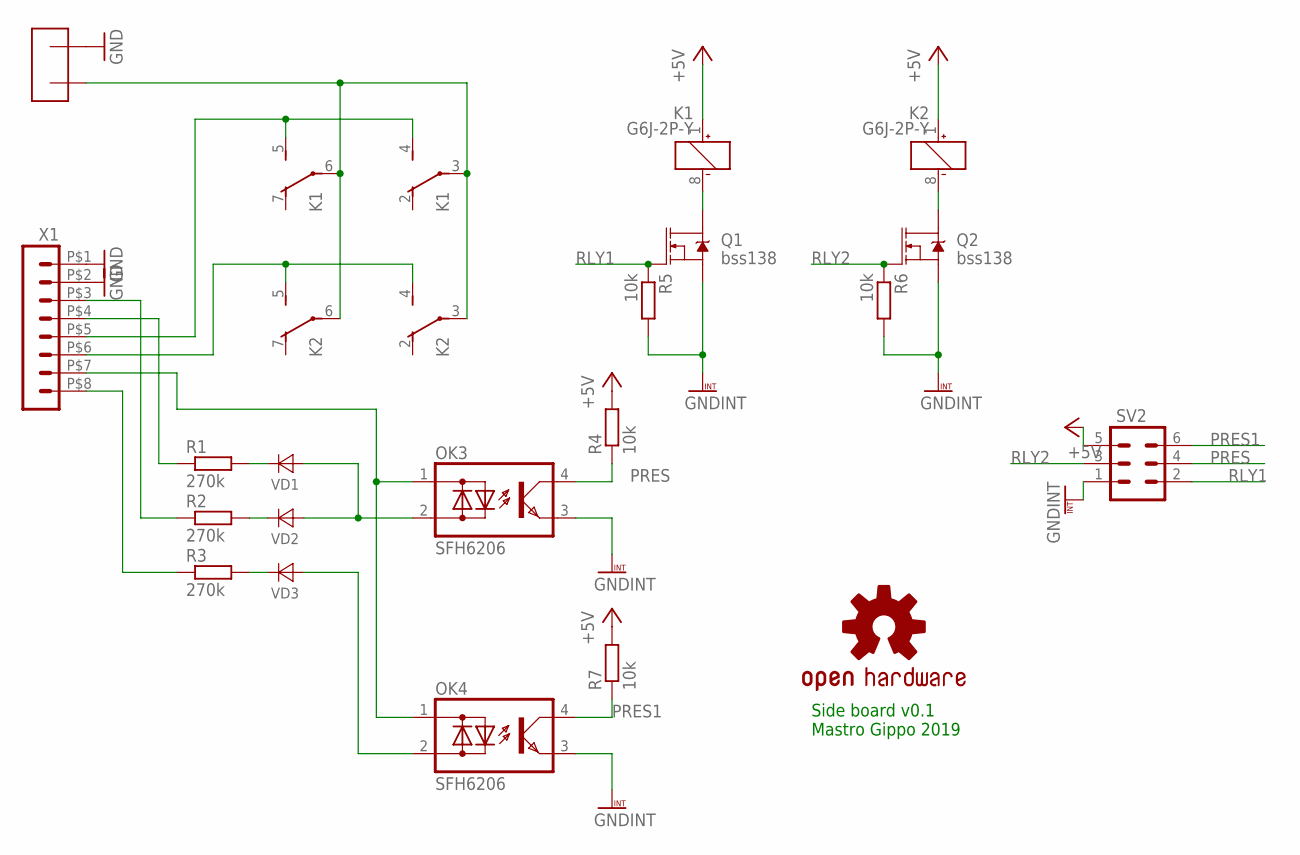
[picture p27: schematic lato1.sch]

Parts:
K1, K2: G6J-2P-Y
OK3, OK4: SFH6206; DIL4-SMD
Q1, Q2: bss138; SOT23-3
R1, R2, R3: 270k; R1210
R4, R5, R6, R7: 10k; R0805
SV2: MA03-2
U$1: ISOLATED_2P; STRIP_NOMIDDLE
U$2: OSHW-LOGOS; OSHW-LOGO-S
VD1, VD2, VD3: DIODE-STANDARD-SOD323; SOD323
X1: HEADER_POS8_43045-0812; 43045-0812

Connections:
+5V: K1.1 (+), K2.1 (+), R4.2, R7.2, SV2.5
GND: U$1.P$1, X1.P$1 (1), X1.P$2 (2)
GNDINT: OK3.3 (E), OK4.3 (E), Q1.2 (S), Q2.2 (S), R5.2, R6.2, SV2.1
unnamed: K1.3, K1.6, K2.3, K2.6, U$1.P$2
unnamed: K1.4 (S), K1.5 (S), X1.P$5 (5)
unnamed: K2.4 (S), K2.5 (S), X1.P$6 (6)
unnamed: R1.1, X1.P$4 (4)
unnamed: R2.1, X1.P$3 (3)
unnamed: R3.1, X1.P$8 (8)
unnamed: OK3.1 (AC1), OK4.1 (AC1), X1.P$7 (7)
unnamed: R1.2, VD1.C
unnamed: R3.2, VD3.C
unnamed: OK4.2 (AC2), VD3.A
unnamed: K1.8 (-), Q1.3 (D)
unnamed: R2.2, VD2.C
unnamed: K2.8 (-), Q2.3 (D)
unnamed: OK3.2 (AC2), VD1.A, VD2.A
PRES: OK3.4 (C), R4.1, SV2.4
PRES1: OK4.4 (C), R7.1, SV2.6
RLY1: Q1.1 (G), R5.1, SV2.2
RLY2: Q2.1 (G), R6.1, SV2.3

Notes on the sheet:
Side board v0.1 Mastro Gippo 2019

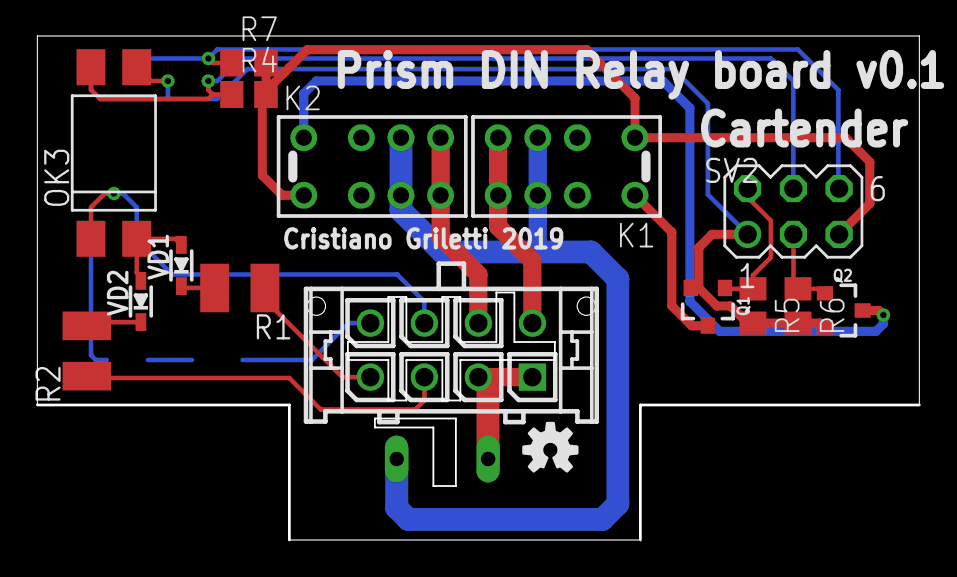
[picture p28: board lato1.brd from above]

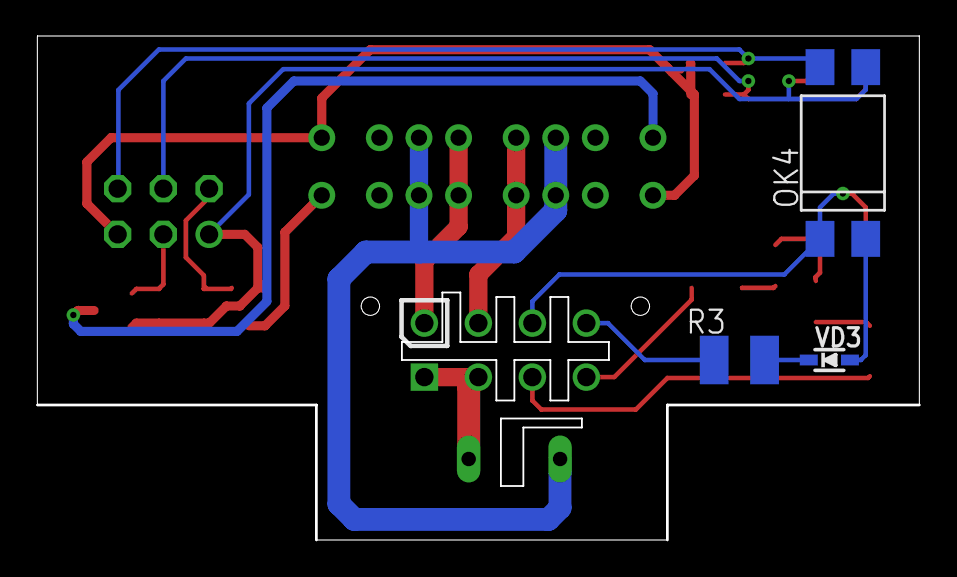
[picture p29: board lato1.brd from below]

Board: 2 copper layers, 49.0 x 28.0 mm, 20 parts (3 on the bottom side), 21 nets.

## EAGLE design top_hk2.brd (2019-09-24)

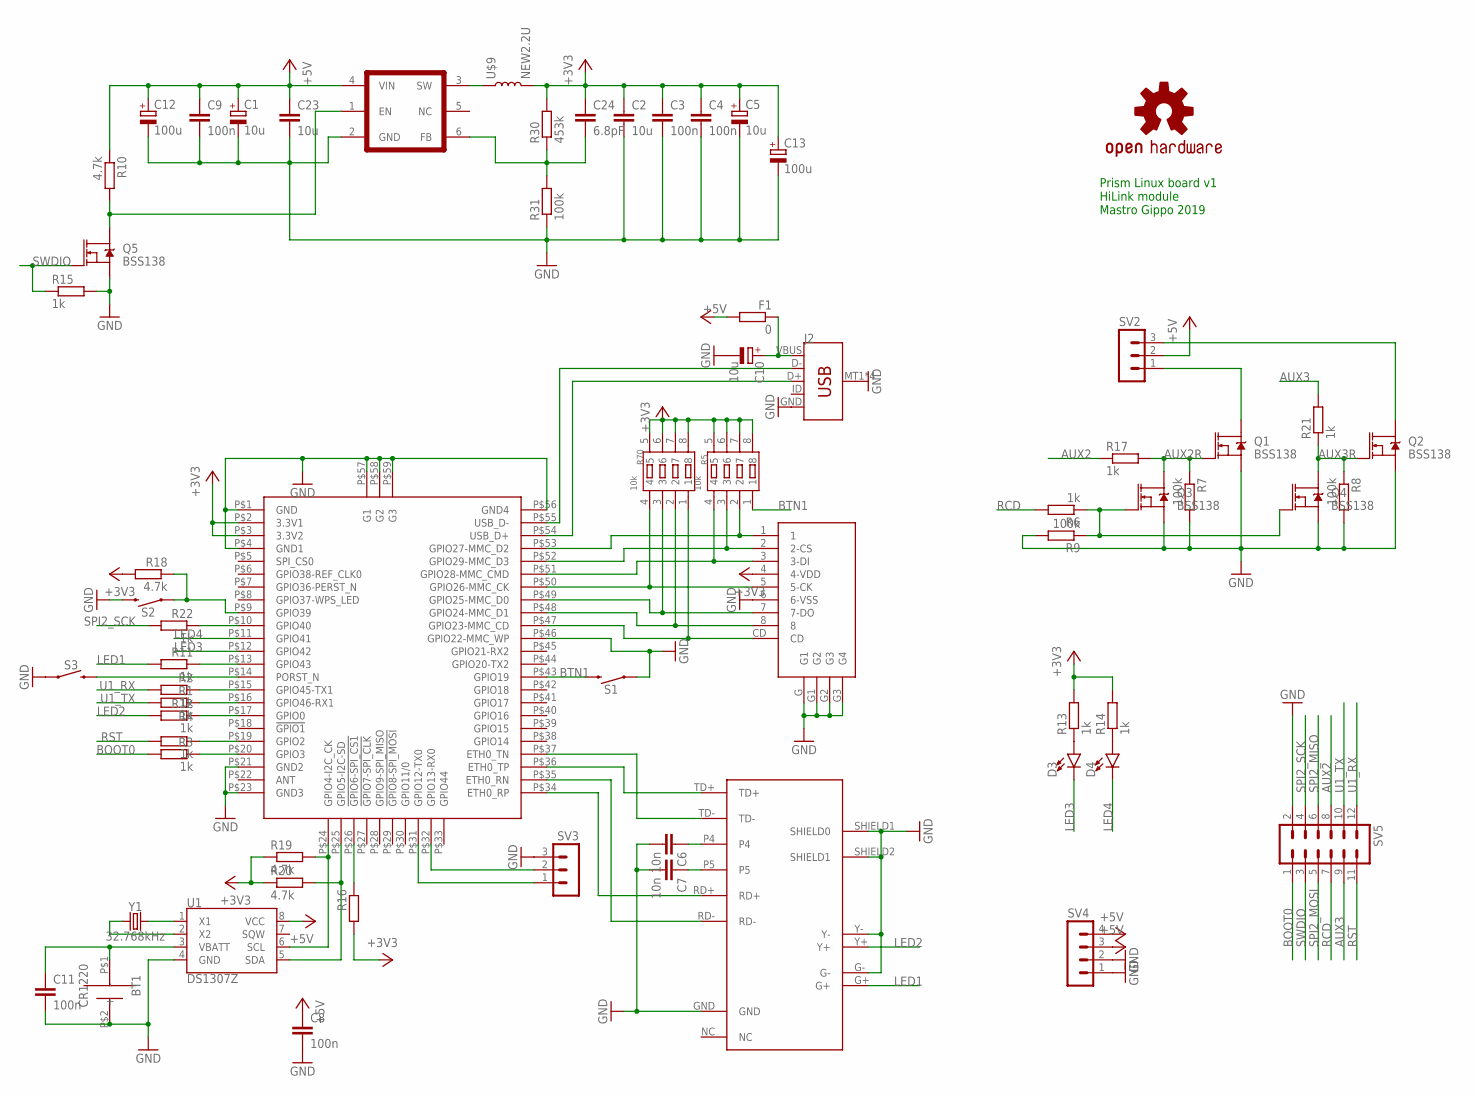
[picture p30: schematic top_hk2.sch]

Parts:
BT1: CR1220
C1, C5, C10: 10u; B/3528-21R
C2, C23: 10u; C0805K
C3, C4, C8, C9, C11: 100n; C0805K
C6, C7: 10n; C0805K
C12, C13: 100u; 153CLV-0505
C24: 6.8pF; C0805K
D3, D4: LED1206; LED-1206
F1: 0; R0603
J2: USB_MICRO-B_SMT; USB-MICROB
Q1, Q2, Q3, Q4, Q5: BSS138; SOT23-3
R1, R2, R3, R4, R6, R11, R12, R13, R14, R15, R17, R21, R22: 1k; R0805
R5, R70: 10k; RA1206-8
R7, R8, R9, R31: 100k; R0805
R10, R18, R19, R20: 4.7k; R0805
R16: R-EU_R0805; R0805
R30: 453k; R0805
S1, S2: MOMENTARY-SWITCH-SPST-SMD-6.0X3.5MM; TACTILE_SWITCH_SMD_6.0X3.5MM
S3: MOMENTARY-SWITCH-SPST-PTH-RIGHT-ANGLE; TACTILE_SWITCH_PTH_RIGHT_ANGLE
SV2, SV3: MA03-1
SV4: MA04-1
SV5: MA06-2
U1: DS1307Z; SO08-0.15
U$1: OSHW-LOGOS; OSHW-LOGO-S
U$2: HLK-7688A
U$3: MICRO_SD; MICRO_SD_C
U$4: HR911105A; RJ45
U$8: TLV62658; SOT23-6
U$9: NEW2.2U; INDUCTOR_4X4MM
Y1: 32.768kHz; CRYSTAL-SMD-2X6-CYL

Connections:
+3V3: C2.1, C3.1, C4.1, C5.+, C13.+, C24.1, R5.5, R5.6, R5.7, R5.8, R13.2, R14.2, R16.2, R18.2, R19.1, R20.1, R30.2, R70.5, R70.6, R70.7, R70.8, U$2.P$2 (3.3V1), U$2.P$3 (3.3V2), U$3.4 (4-VDD), U$9.P$2 (2)
+5V: C1.+, C8.1, C9.1, C12.+, C23.1, F1.2, R10.1, SV2.2, SV4.3, SV4.4, U1.8 (VCC), U$8.4 (VIN)
AUX2: R17.1, SV5.8
AUX2R: Q1.1 (G), Q3.3 (D), R7.1, R17.2
AUX3: R21.2, SV5.9
AUX3R: Q2.1 (G), Q4.3 (D), R8.1, R21.1
BOOT0: R3.2, SV5.1
BTN1: R5.1, S1.2, U$2.P$43 (GPIO19)
GND: BT1.P$2 (-), C1.-, C2.2, C3.2, C4.2, C5.-, C6.2, C7.2, C8.2, C9.2, C10.-, C11.2, C12.-, C13.-, C23.2, J2.GND, J2.MT1 (SHIELD), J2.MT2 (SHIELD), J2.P$1 (SHIELD), J2.P$2 (SHIELD), Q1.2 (S), Q2.2 (S), Q3.2 (S), Q4.2 (S), Q5.2 (S), R7.2, R8.2, R9.2, R15.2, R31.1, S1.1, S2.2, S3.1, SV3.3, SV4.1, SV4.2, SV5.2, U1.4 (GND), U$2.P$1 (GND), U$2.P$4 (GND1), U$2.P$21 (GND2), U$2.P$23 (GND3), U$2.P$46 (GPIO22-MMC_WP), U$2.P$56 (GND4), U$2.P$57 (G1), U$2.P$58 (G2), U$2.P$59 (G3), U$3.6 (6-VSS), U$3.G (G1), U$3.G1 (G2), U$3.G2 (G3), U$3.G3 (G4), U$4.G-, U$4.GND, U$4.SHIELD1 (SHIELD0), U$4.SHIELD2 (SHIELD1), U$4.Y-, U$8.2 (GND)
LED1: R11.2, U$4.G+
LED2: R12.2, U$4.Y+
LED3: D3.C, U$2.P$12 (GPIO42)
LED4: D4.C, U$2.P$11 (GPIO41)
unnamed: C6.1, U$4.P4
unnamed: C7.1, U$4.P5
unnamed: R2.1, U$2.P$15 (GPIO45-TX1)
unnamed: R1.1, U$2.P$16 (GPIO46-RX1)
unnamed: R5.3, U$2.P$52 (GPIO29-MMC_D3), U$3.2 (2-CS)
unnamed: R5.4, U$2.P$51 (GPIO28-MMC_CMD), U$3.3 (3-DI)
unnamed: R5.2, U$2.P$53 (GPIO27-MMC_D2), U$3.1
unnamed: R70.4, U$2.P$50 (GPIO26-MMC_CK), U$3.5 (5-CK)
unnamed: U$2.P$36 (ETH0_TP), U$4.TD+
unnamed: R19.2, U1.6 (SCL), U$2.P$24 (GPIO4-I2C_CK)
unnamed: R20.2, U1.5 (SDA), U$2.P$25 (GPIO5-I2C-SD)
unnamed: R4.1, U$2.P$19 (GPIO2)
unnamed: R3.1, U$2.P$20 (GPIO3)
unnamed: R70.2, U$2.P$48 (GPIO24-MMC_D1), U$3.8
unnamed: R11.1, U$2.P$13 (GPIO43)
unnamed: Q5.3 (D), R10.2, U$8.1 (EN)
unnamed: SV3.2, U$2.P$32 (GPIO13-RX0)
unnamed: SV3.1, U$2.P$31 (GPIO12-TX0)
unnamed: R16.1, U$2.P$26 (!GPIO6-SPI_CS1)
unnamed: R18.1, S2.1, U$2.P$9 (GPIO39)
unnamed: R22.1, U$2.P$10 (GPIO40)
unnamed: D3.A, R13.1
unnamed: D4.A, R14.1
unnamed: S3.2, U$2.P$14 (PORST_N)
unnamed: Q3.1 (G), Q4.1 (G), R6.1, R9.1
unnamed: J2.D+, U$2.P$54 (USB_D+)
unnamed: J2.D-, U$2.P$55 (USB_D-)
unnamed: C10.+, F1.1, J2.VBUS
unnamed: R70.1, U$2.P$47 (GPIO23-MMC_CD), U$3.CD
unnamed: R70.3, U$2.P$49 (GPIO25-MMC_D0), U$3.7 (7-DO)
unnamed: U1.2 (X2), Y1.X1 (1)
unnamed: U1.1 (X1), Y1.X2 (2)
unnamed: BT1.P$1 (+), C11.1, U1.3 (VBATT)
unnamed: Q1.3 (D), SV2.1
unnamed: U$2.P$37 (ETH0_TN), U$4.TD-
unnamed: U$2.P$35 (ETH0_RN), U$4.RD-
unnamed: U$8.3 (SW), U$9.P$1 (1)
unnamed: U$2.P$34 (ETH0_RP), U$4.RD+
unnamed: Q2.3 (D), SV2.3
unnamed: R12.1, U$2.P$17 (GPIO0)
unnamed: C24.2, R30.1, R31.2, U$8.6 (FB)
RCD: R6.2, SV5.7
RST: R4.2, SV5.11
SPI2_MISO: SV5.6
SPI2_MOSI: SV5.5
SPI2_SCK: R22.2, SV5.4
SWDIO: Q5.1 (G), R15.1, SV5.3
U1_RX: R2.2, SV5.12
U1_TX: R1.2, SV5.10

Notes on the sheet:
Prism Linux board v1 HiLink module Mastro Gippo 2019

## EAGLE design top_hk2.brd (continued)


Board: 2 copper layers, 86.4 x 49.8 mm, 65 parts (1 on the bottom side), 60 nets.

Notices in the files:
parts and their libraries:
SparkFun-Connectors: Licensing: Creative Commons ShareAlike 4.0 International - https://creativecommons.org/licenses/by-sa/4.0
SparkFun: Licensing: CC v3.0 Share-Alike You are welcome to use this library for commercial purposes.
